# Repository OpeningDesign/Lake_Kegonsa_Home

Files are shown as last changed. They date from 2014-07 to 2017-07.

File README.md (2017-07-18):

Lake Kegonsa House
---

A major house renovation on [Lake Kegonsa](https://www.google.com/maps/place/3232+Aalseth+Ln,+Stoughton,+WI+53589/@42.94901,-89.25464,17z/data=!3m1!4b1!4m2!3m1!1s0x88064f5076276249:0x2fda5a143436c772)

Similar to our [IFCopenHouse](https://github.com/OpeningDesign/IFCopenHouse_Lantern_Hollow) we're using this open source project to try and push [openBIM](http://www.buildingsmart.org/standards/technical-vision/) even further.

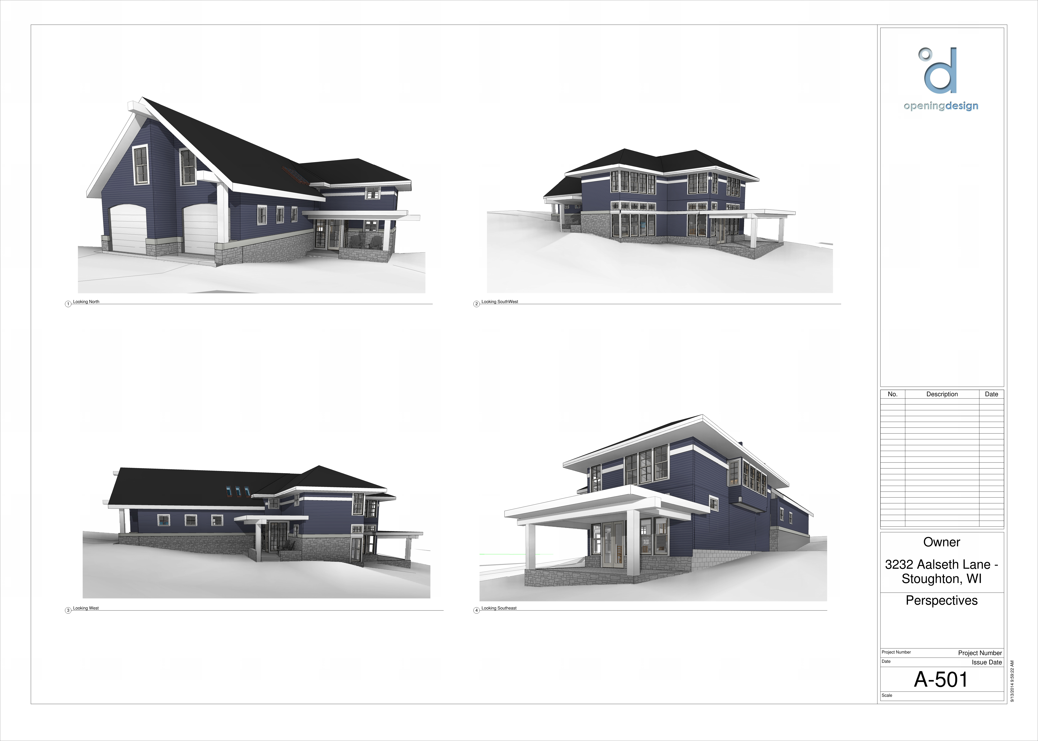
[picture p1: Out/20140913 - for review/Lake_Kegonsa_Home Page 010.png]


---
We are always looking to collaborate with a select team of individuals who are also excited about the benefits of working  <a href="#in-the-open">in the open</a> and pushing the bounds of existing and new IFC workflows.

One of our mantras is, "Specialize, Specialize, Specialize!".  Over the years we would like to build a trusted network of highly specialized collaborators agile enough to tackle the most obscure problems.

Although, currently we're looking for a **structural engineer** to collaborate with on this project, if you're a AEC consultant also interested in this 'open' way of working, shoot us an email at <ahref="mailto:hello@openingdesign.com">hello@openingdesign.com</a>. It would be great to work with you in the future.

* Architectural Technologist
* Civil Engineer
* Code Expediter/Consultant
* Electrical Engineer
* Energy Conservation Consultant
* Environmental Engineer
* Estimators
* Fabricators
* Geotechnical Engineer
* Landscape Architect
* Lighting Designer
* Mechanical Engineer
* Plumbing Engineer
* Specification Writer
* Structural Engineer
* Sub-contractors
* And of course, most importantly, *Building & Facility Owners*. :)

---
#### In-the-Open

All of OpeningDesign's projects are conducted out in the open.  That is, during the development of any one project, all team communication and content is hosted [publicly](https://github.com/OpeningDesign) and is <a href="#license">open source</a>.

Since we believe that [innovation happens elsewhere](https://www.google.com/search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) we would like to lower, as much as possible, the barrier for others to collaborate and contribute.

---
#### License
Per usual, all [OpeningDesign](http://openingdesign.com) content is licensed under an open source, 'copyleft' license: 
Attribution-ShareAlike 4.0 International (CC BY-SA 4.0)


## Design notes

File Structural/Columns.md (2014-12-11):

**Column Analysis. Columns at Axis 3, Axis 7**

**1. Sketch.**

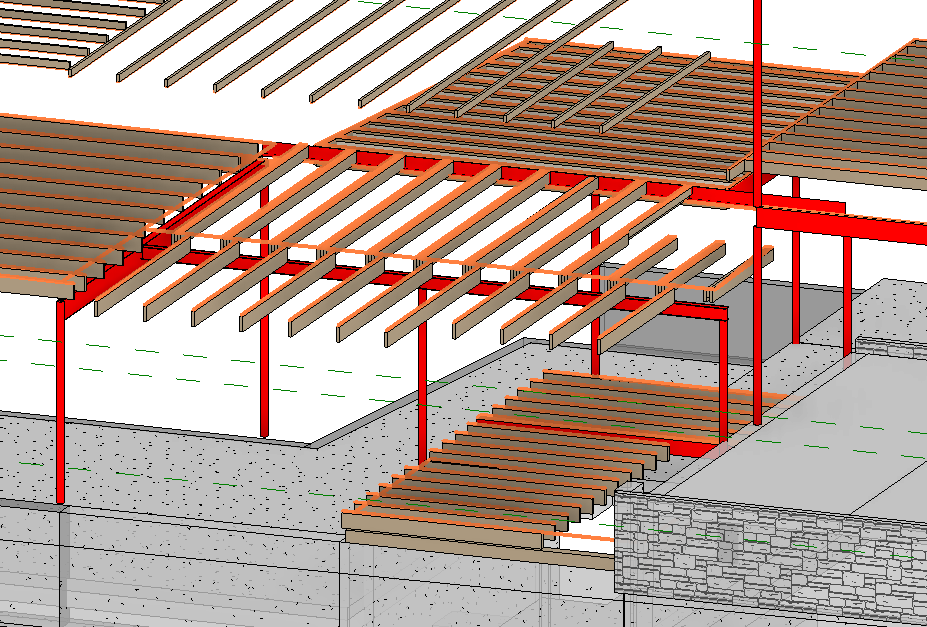
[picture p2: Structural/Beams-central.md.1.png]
Sketch


**2. Input Summary.**

2.1. Applicable codes.
2.1.1. Wisconsin Administrative Code, Chapter SPS 321 – Uniform Dwelling Code
2.1.2. ASCE 07-05, Minimum Loads on Buildings
2.1.3. AISC 360-05, Specification for Structural Steel Buildings

2.2. Design considerations.
As per 2.1.1, allowable stress design (ASD) is performed for steel elements using 2.1.3.

2.3. Load values

Dead Load Calculation:
Minimum value: 							Dmin = 10 psf;
Flooring: Wood Joists w/ Wood flooring 	D1 = approx. 12 psf;
Walls: light-frame wood walls			D2 = approx 6 psf
Max D1+D2+D3 & Dmin						D = D1+D2 = 18 psf

D = 18 psf		as per WAC Chapter SPS 321, calculation
L = 40 psf		as per WAC Chapter SPS 321 Table 321.02

**3. Structural Design.**

3.1 Columns at gridline (4).

3.1.1. Column at gridline (4D)

	Material 		= A500 Steel ASTM.
	Unbraced length = 7.58'

Loads Calculation from Beams-Central reactions calc (3.2.1):

	Total Point Load 	= R1 = 4.57 kip
	Dead Load 			= 1.4 		kip
	Live Load			= 3.17 		kip

ASD Design as per 2.1.1. SPS 

	Section		= HSS3.5X.188
	Fy			= 42 ksi
	Fu			= 58 ksi
	Compression/buckling checks apply.

3.1.2. Column at gridline (4F)

	Material 		= A500 Steel ASTM.
	Unbraced length = 7.58'

Loads Calculation from Beams-Central reactions calc (R2 from 3.2.1):

	Total Point Load 	= R2 	= 13.84 	kip
	Dead Load 					= 4.33 		kip
	Live Load					= 9.51 		kip

ASD Design as per 2.1.1. SPS 

	Section		= HSS3.5X.188
	Fy			= 42 ksi
	Fu			= 58 ksi
	Compression/buckling checks apply.

3.1.3. Column at gridline (4H)

	Material 		= A500 Steel ASTM.
	Unbraced length = 9.9'

Loads Calculation from Beams-Central reactions calc (R3 from 3.2.1, R2 from 3.3.1):

	Total Point Load 	= R3 +R2	= 3.67+5.33 = 9.0 	kip
	Dead Load 									= 2.8 	kip
	Live Load									= 6.2 	kip

ASD Design as per 2.1.1. SPS 

	Section		= HSS3.5X.188
	Fy			= 42 ksi
	Fu			= 58 ksi
	Compression/buckling checks apply.

3.2. Columns at gridline (2).

Material:	A500 Steel ASTM.

	Unbraced length = 11.3’

Loads Calculation (worst case)

	Load Area 		= 14 x 8 = 112 sf.
	Dead Load 		= 112 x 18 = 2.1 kip
	Live Load		= 112 x 40= 4.5 kip

ASD Design as per 2.1.1. SPS 

Section		= HSS3.5X.188

	Fy			= 42 ksi
	Fu			= 58 ksi
	Compression/buckling checks apply.

**4. Design Results**
	
4.1 Columns at gridline (4).

Unbraced: 		= A500 Gr. B Steel, HSS Shape HSS3.5X.188 (see Calculation 3.1.)

4.2. Columns at gridline (2).

Unbraced: 		= A500 Gr. B Steel, HSS Shape HSS3.5X.188 (see Calculation 3.2.)

Calculation 3.1.

Only governing calculation for columns (4F) and (4H) are shown

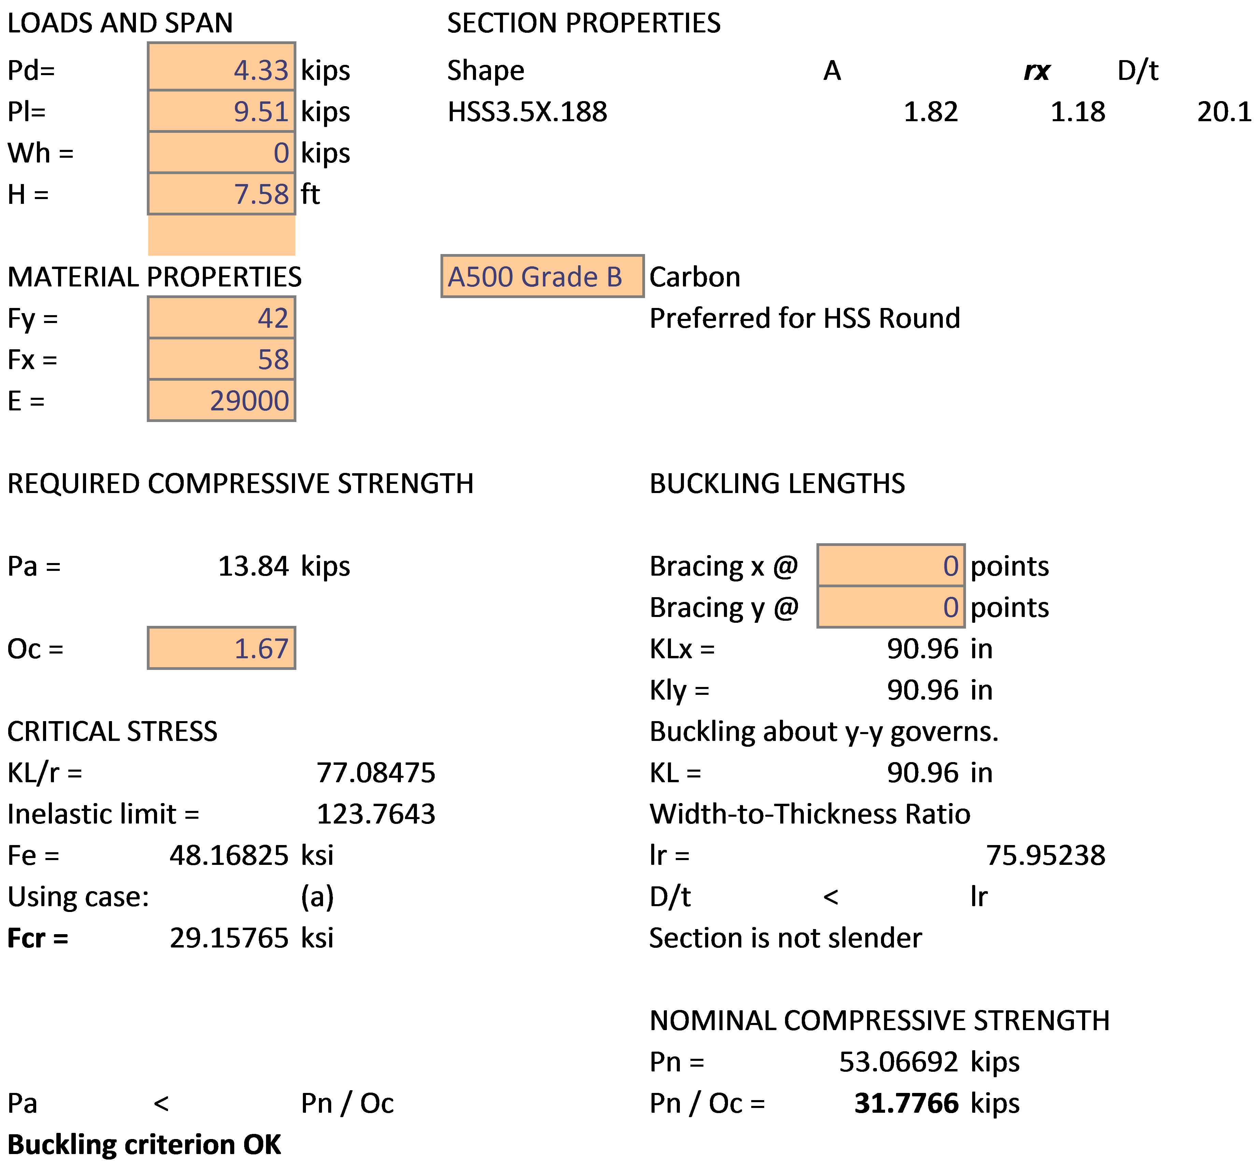
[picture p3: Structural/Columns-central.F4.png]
Calc 3.1.2


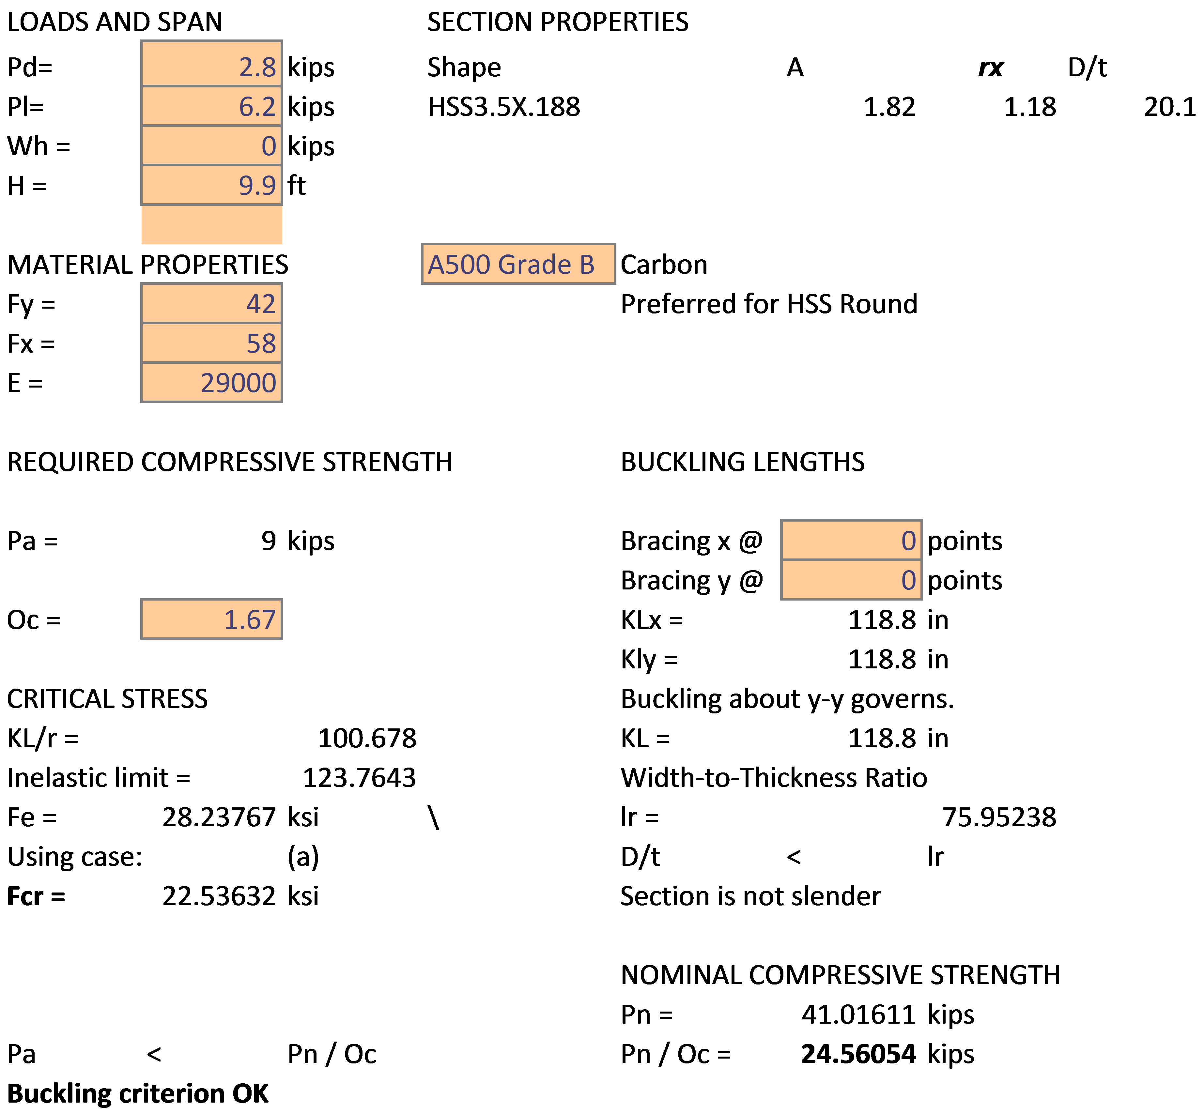
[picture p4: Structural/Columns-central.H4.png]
Calc 3.1.3


Calculation 3.2.
 
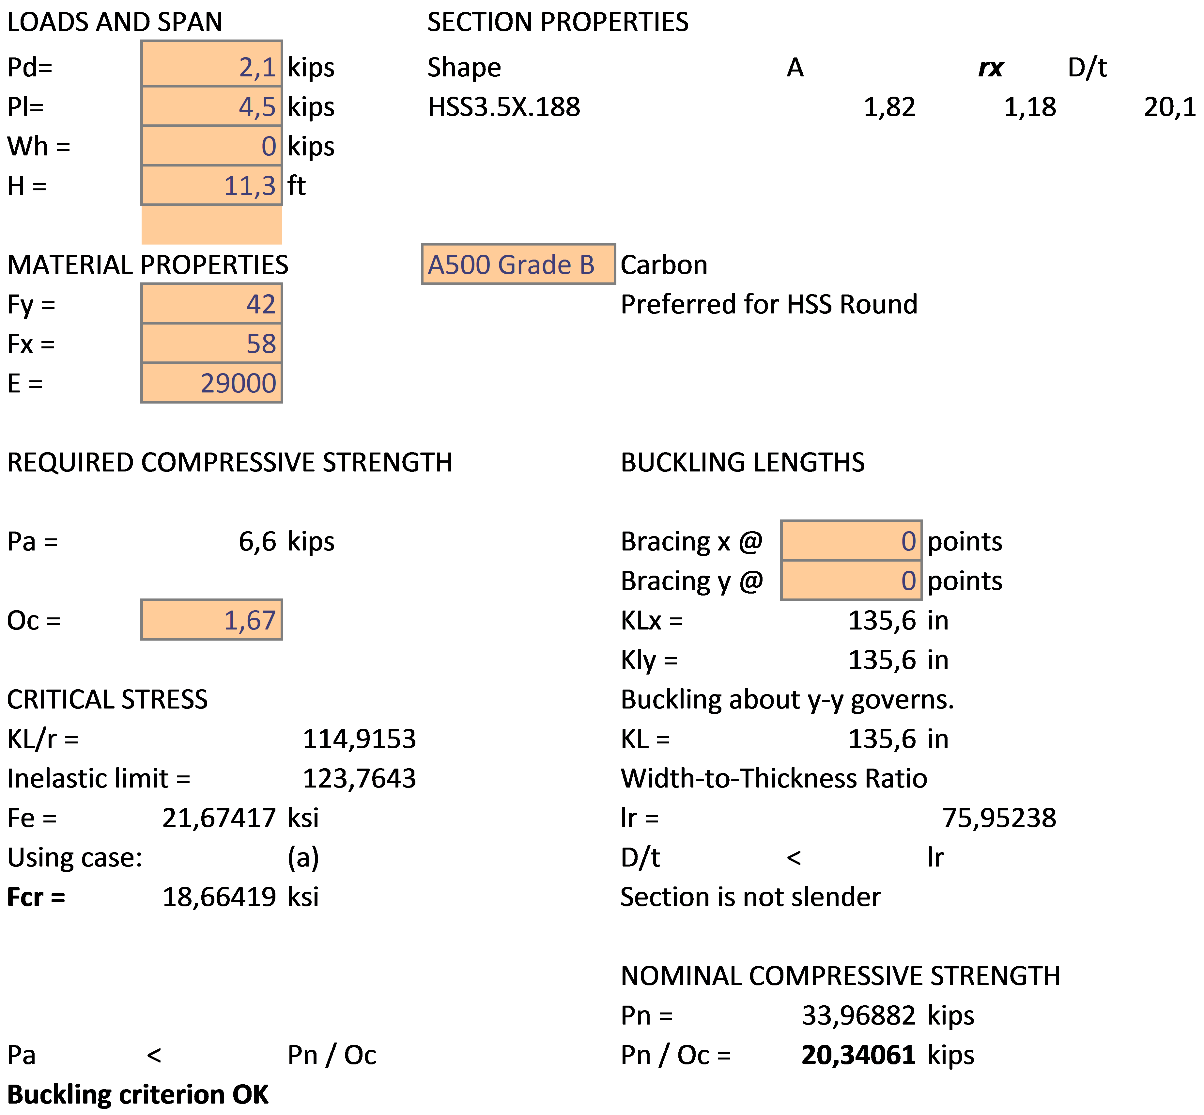
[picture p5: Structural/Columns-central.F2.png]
Calc 3.2


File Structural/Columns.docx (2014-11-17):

Column Analysis. Columns at Axis 3, Axis 7

1. Sketch.


2. Input Summary.

2.1. Applicable codes.
2.1.1. Wisconsin Administrative Code, Chapter SPS 321 – Uniform Dwelling Code
2.1.2. ASCE 07-05, Minimum Loads on Buildings
2.1.3. AISC 360-05, Specification for Structural Steel Buildings

2.2. Design considerations.

As per 2.1.1, allowable stress design (ASD) is performed for steel elements using 2.1.3.

2.3. Load values

Dead Load Calculation:

Minimum value: Dmin = 10 psf;

Flooring: Wood Joists w/ Wood flooring D1 = approx. 12 psf;

Walls: light-frame wood walls D2 = approx 6 psf

Max D1+D2+D3 & Dmin D = D1+D2 = 18 psf

D = 18 psf as per WAC Chapter SPS 321, calculation
L = 40 psf as per WAC Chapter SPS 321 Table 321.02

3. Structural Design.

3.1. Columns at Axis 3.

Material: A500 Steel ASTM.

Unbraced length = 8.2’

Loads Calculation (worst case)

Load Area = 13 x 11.5 = 150 sf.

Dead Load = 150 x 18 = 2.7 kip

Live Load = 150 x 40= 6 kip

AISC Check

ASD Design as per 2.1.1. SPS

Section = HSS3.5X.188

Fy = 42 ksi

Fu = 58 ksi

Compression/buckling checks apply.

3.1. Columns at Axis 7.

Material: A500 Steel ASTM.

Unbraced length = 11.3’

Loads Calculation (worst case)

Load Area = 14 x 8 = 112 sf.

Dead Load = 112 x 18 = 2.1 kip

Live Load = 112 x 40= 4.5 kip

AISC Check

ASD Design as per 2.1.1. SPS

Section = HSS3.5X.188

Fy = 42 ksi

Fu = 58 ksi

Compression/buckling checks apply.

4. Design Results

4.1 Columns at Axis 3.

Unbraced: = A500 Gr. B Steel, HSS Shape HSS3.5X.188 (see Calculation 3.1.)

4.2. Columns at Axis 7.

Unbraced: = A500 Gr. B Steel, HSS Shape HSS3.5X.188 (see Calculation 3.2.)

Calculation 3.1.

Calculation 3.2.

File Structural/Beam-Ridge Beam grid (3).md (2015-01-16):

# 1. Sketch.

Sketch

# 2. Input Summary.

## 2.1. Applicable codes.  
2.1.1. Wisconsin Administrative Code, Chapter SPS 321 – Uniform Dwelling Code  
2.1.2. ASCE 07-05, Minimum Loads on Buildings    
  
## 2.2. Design considerations.

Span tables are used to determine minimal section.

Reference design: Weyerhaeuser Microllam LVL Beams p.14-15

<http://www.woodbywy.com/document/TJ-9000/>

## 2.3. Load values

S = 30 (22,5) psf	as per 2.1.1 SPS 321.27

W = 15 psf

## 3. Structural Design.

    Rafter Span = 12'
    Column Span = 16.8'
    Largest cantilever length = 10'5"
    Slope 10”/12” = 40°
	30 psf Live Load
	15 psf Dead Load
		
## 4. Design Results

Preliminary span tables results (excluding cantilever):

    Ridge Beam along Grid (3):
	Section: 3.5" x 14"

	Applicable Materials:
	1) 1.55E TimberStrand® LSL 
	2) 2.0E Microllam® LVL
	3) 2.0E Parallam® PSL

FINAL span tables results (including cantilever):
	
From max distributed load values derived from span tables:

	W = M / 50 = 12.13 * 2 / 50 = 0.49 kip/ft
	W = V / 10 = 4.6 * 2 / 10 = 0.92 kip/ft

Moment governs section design.

Considering span and cantilever moments equality:

	wl^2/8 = wa^2/2 => l = 2a,

Equivalent column span for cantilevered beam is:

	l = 2a = 2 * 10'5" = 21 ft
    
    Ridge Beam along Grid (3) Result:
	Section: 3½" x 16" OR 5¼" x 14"

	Applicable Materials:
	1) 2.0E Microllam® LVL
	)2 2.0E Parallam® PSL

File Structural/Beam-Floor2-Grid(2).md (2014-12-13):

# 1. Sketch.

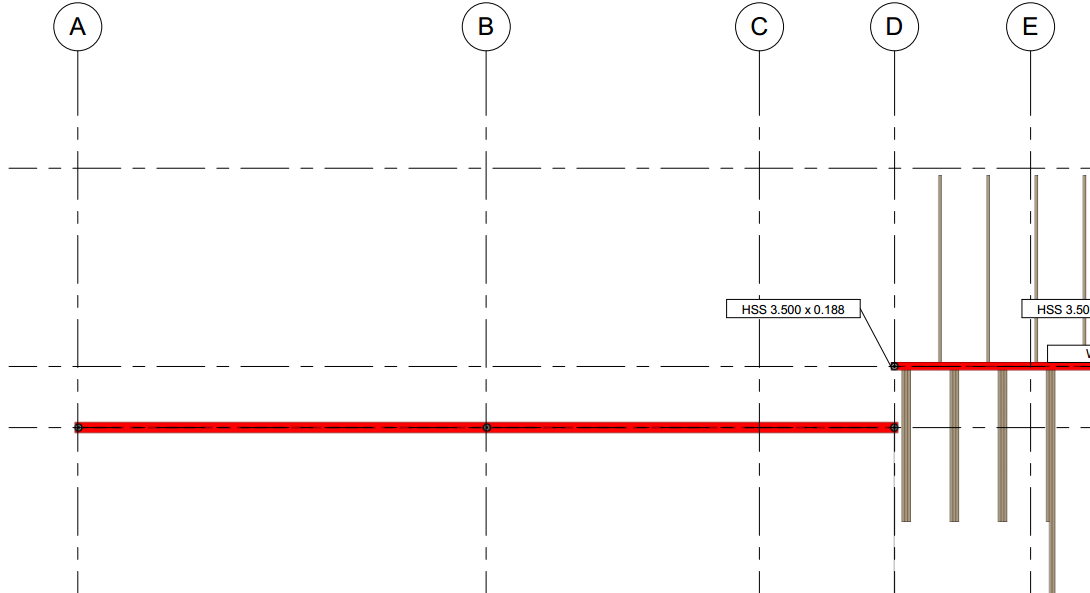
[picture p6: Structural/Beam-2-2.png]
Sketch


# 2. Input Summary.

## 2.1. Applicable codes.  
2.1.1. Wisconsin Administrative Code, Chapter SPS 321 – Uniform Dwelling Code  
2.1.2. ASCE 07-05, Minimum Loads on Buildings  
2.1.3. AISC 360-05, Specification for Structural Steel Buildings  

## 2.2. Design considerations.

As per 2.1.1, allowable stress design (ASD) is performed for steel elements using 2.1.3.

## 2.3. Load values

### Dead Load Calculation:

Minimum value:                 Dmin = 10 psf;

Dead Load, Roof:

    Minimum value:                 Dmin = 10 psf;
    Flooring: Wood Joists w/ Wood flooring     D1 = approx. 12 psf;
    Walls: light-frame wood walls        D2 = approx 6 psf;
    Max D1+D2 & Dmin            **D = D1+D2 = 18 psf**

### Live Load Calculation:

**L** = 40 psf        as per WAC Chapter SPS 321 Table 321.02

**D** = 18 psf        
**L** = 40 psf        

## 2.4. Load calculation

    Load span 1 = 6'

    Load span 2 = 7'

    Load length = 16.7'

    Load area = (6+7)*16.7 = 217.1 sq.ft.

    D = 18 * 13 = 0.234 kip/ft

    L = 40 * 13 = 0.520 kip/ft

## 3. Structural Design.

    Initial material:    A99 Steel ASTM.

    Beam span = 16.7'

AISC Check

    ASD Design as per 2.1.1. SPS

Section        = **W8X24**

    All considered sections are compact, Y and LBW checks apply.

Unbraced beam at (C):  = A992 Steel, W Shape **W8X24** (see Calculation)

## Calculation

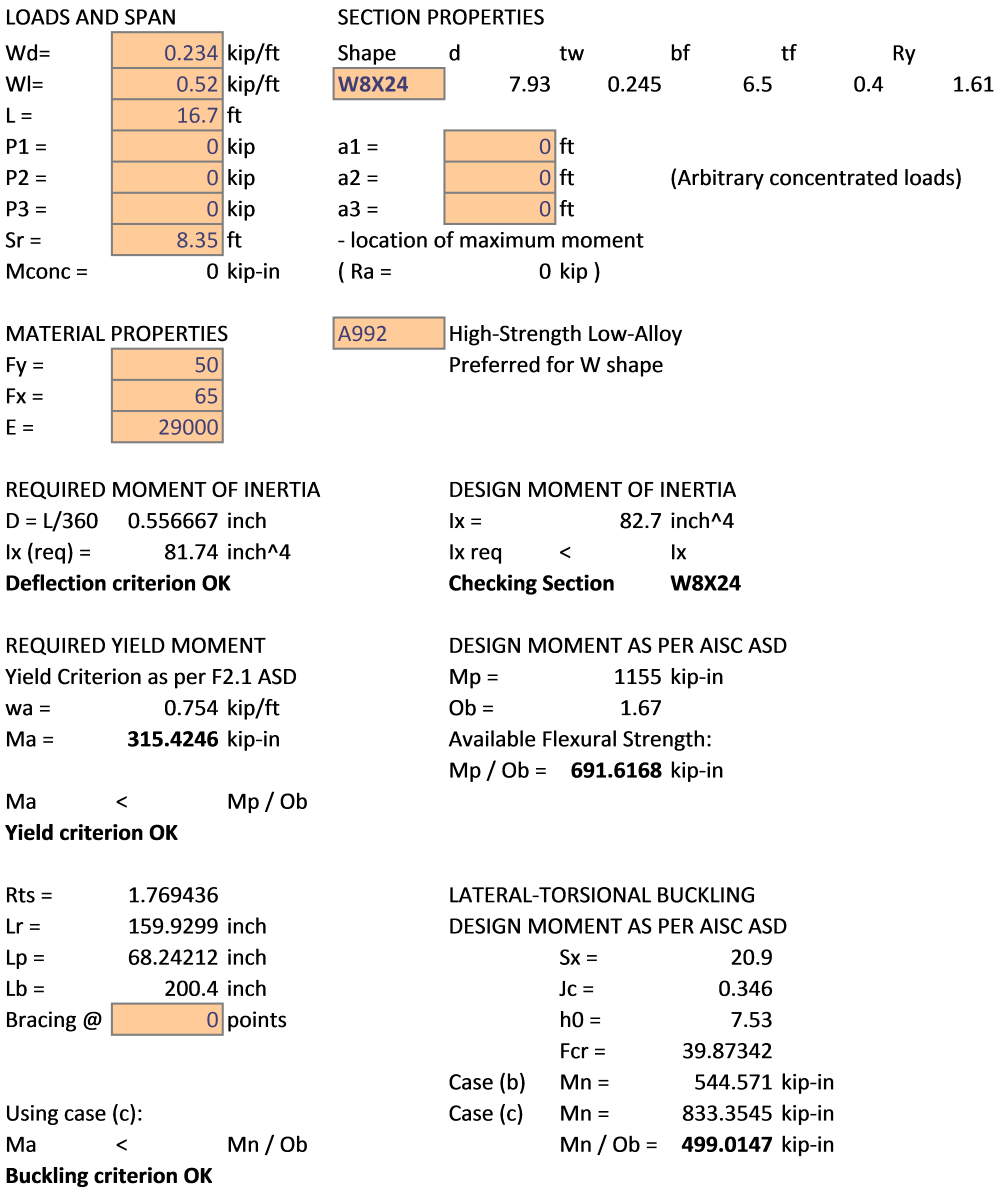
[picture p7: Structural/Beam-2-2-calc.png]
Calculation


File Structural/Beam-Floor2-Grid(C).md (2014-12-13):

# 1. Sketch.

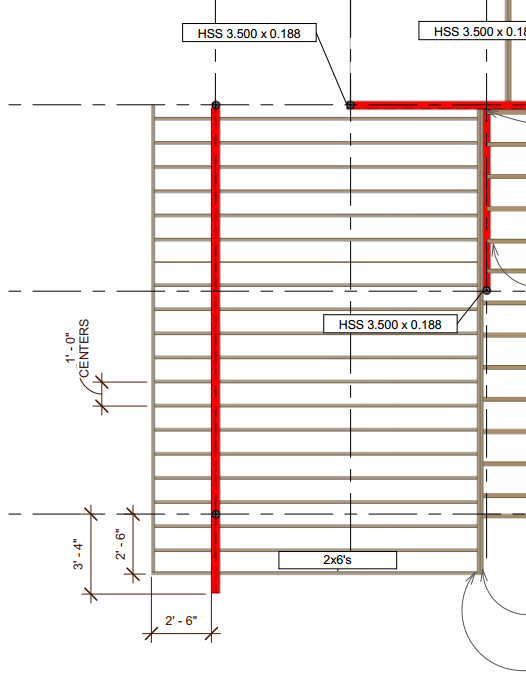
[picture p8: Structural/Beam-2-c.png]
Sketch


# 2. Input Summary.

## 2.1. Applicable codes.  
2.1.1. Wisconsin Administrative Code, Chapter SPS 321 – Uniform Dwelling Code  
2.1.2. ASCE 07-05, Minimum Loads on Buildings  
2.1.3. AISC 360-05, Specification for Structural Steel Buildings  

## 2.2. Design considerations.

As per 2.1.1, allowable stress design (ASD) is performed for steel elements using 2.1.3.

## 2.3. Load values

### Dead Load Calculation:

Minimum value:                 Dmin = 10 psf;

Dead Load, Roof:

Minimum value:          Dmin = 10 psf;

Rafters                 D1 = 3 psf;

Plywood & sheathing     D2 = 3psf/inch * 0.75 = 2.25 psf

Roofing                 D3 = 2 psf

Max D1+D2+D3 & Dmin     **D = 10 psf**

### Dead Load Calculation:

Snow Load				= **24.3 psf** per calculation

**D** = 10 psf        
**L** = 24.3 psf        

## 2.4. Load calculation

    Load span 1 = 2.5'

    Load span 2 = 10.0'

    Load length = 20.58'

    Load area = 12.5 * 20.58 = 257.3 sq.ft.

    D = 10 * 12.5 = 0.125 kip/ft

    L = 24.3 * 12.5 = 0.304 kip/ft

## 3. Structural Design.

    Initial material:    A99 Steel ASTM.

    Beam span = 17.0'

AISC Check

    ASD Design as per 2.1.1. SPS

Section        = **W8X18**

    All considered sections are compact, Y and LBW checks apply.

Unbraced beam at (C):  = A992 Steel, W Shape **W8X18** (see Calculation)

## Calculation

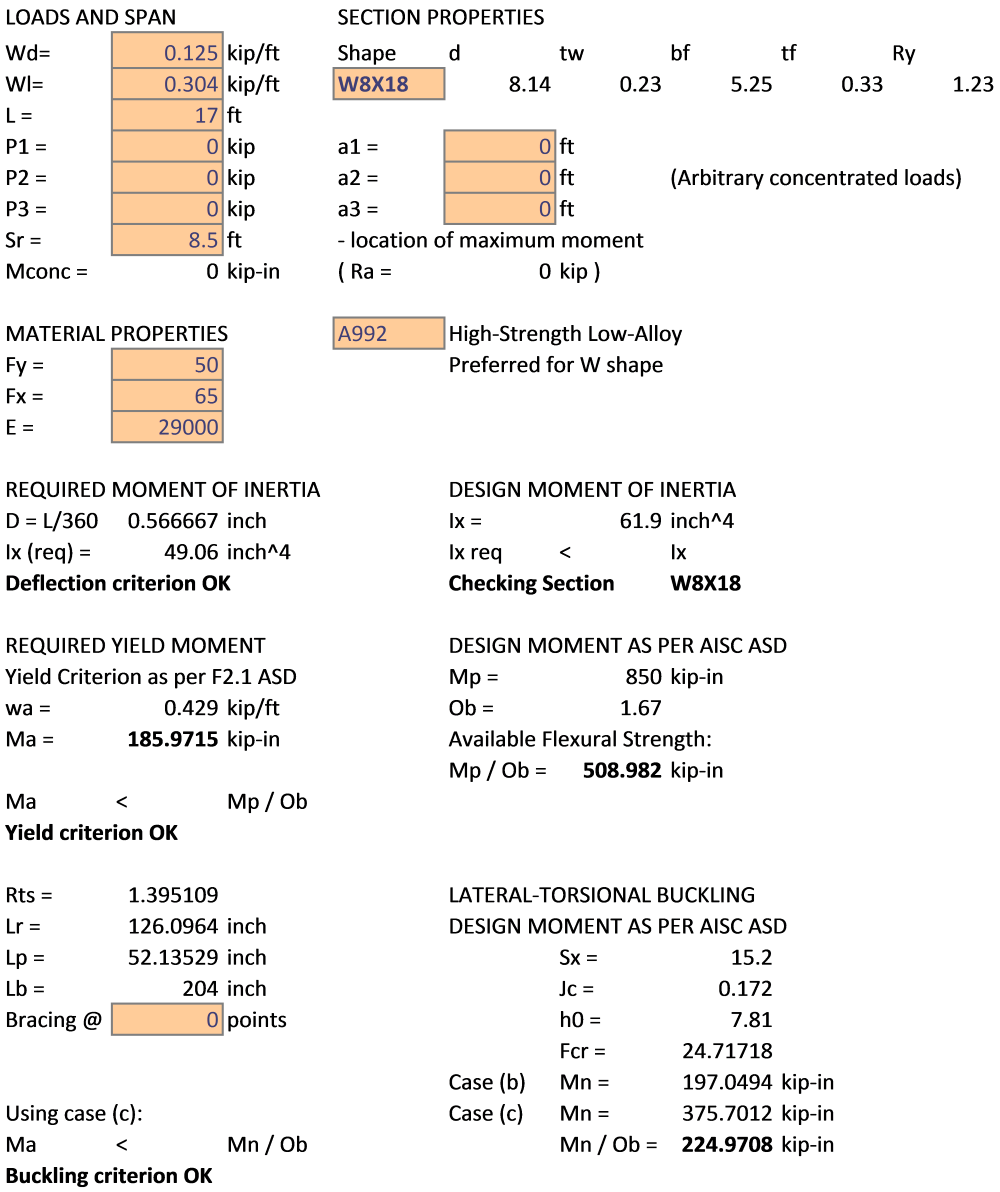
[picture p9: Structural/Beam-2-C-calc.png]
Calculation


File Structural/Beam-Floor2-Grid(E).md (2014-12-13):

# 1. Sketch.

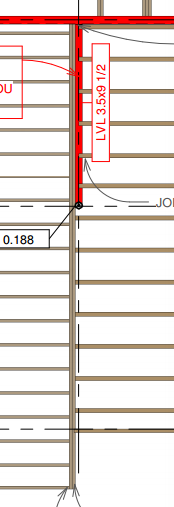
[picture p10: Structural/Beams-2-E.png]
Sketch


# 2. Input Summary.

## 2.1. Applicable codes.  
2.1.1. Wisconsin Administrative Code, Chapter SPS 321 – Uniform Dwelling Code  
2.1.2. ASCE 07-05, Minimum Loads on Buildings  
2.1.3. AISC 360-05, Specification for Structural Steel Buildings  

## 2.2. Design considerations.

Span tables are used to determine minimal section.

Reference design: Weyerhaeuser Microllam LVL Beams p.14-15

<http://www.woodbywy.com/document/TJ-9000/>

## 2.3. Load values

Dead Load Calculation:

Minimum value:                 Dmin = 10 psf;

Flooring: Wood Joists w/ Wood flooring     D1 = approx. 12 psf;

Walls: light-frame wood walls        D2 = approx 6 psf

Max D1+D2+D3 & Dmin            **D = D1+D2 = 18 psf**

**D** = 18 psf        as per WAC Chapter SPS 321, calculation  
**L** = 40 psf        as per WAC Chapter SPS 321 Table 321.02

## 3. Structural Design.

    Load Span 1 = 10.67'

    Load Span 2 = 17.0'

    Beam Span = 8.67'

## 4. Design Results

Floor 2 – Beam at grid (E):

Minimum design section 3.5" x 9.5"

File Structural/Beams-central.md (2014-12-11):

**1. Sketch.**

Sketch

**2. Input Summary.**

2.1. Applicable codes.  
2.1.1. Wisconsin Administrative Code, Chapter SPS 321 – Uniform Dwelling Code  
2.1.2. ASCE 07-05, Minimum Loads on Buildings  
2.1.3. AISC 360-05, Specification for Structural Steel Buildings  

2.2. Design considerations.

As per 2.1.1, allowable stress design (ASD) is performed for steel elements using 2.1.3.

2.3. Load values

Dead Load Calculation:

Minimum value:                 Dmin = 10 psf;

Flooring: Wood Joists w/ Wood flooring     D1 = approx. 12 psf;

Walls: light-frame wood walls        D2 = approx 6 psf

Max D1+D2+D3 & Dmin            **D = D1+D2 = 18 psf**

Snow Load				= **15.9 psf**

**D** = 18 psf        as per WAC Chapter SPS 321, calculation  
**L** = 40 psf        as per WAC Chapter SPS 321 Table 321.02

**3. Structural Design.**

3.1. Floor 2, Central Beam Design – Beam at grid (2).

3.1.1 Span 1

    Initial material:    A99 Steel ASTM.

    Span = 12.5'

    Length = 24.4'

Loads Calculation

    Load Area         = 12.5 x 12 = 150 sf.

    Dead Load         = 150 x 18 / 12.5 = 216 pf = 0.22 kip/ft

    Live Load        = 150 x 40 /12.5 = 480 pf = 0.48 kip/ft

AISC Check

    ASD Design as per 2.1.1. SPS

Section        = **W6X16**

    Fy            = 50 ksi

    Fu            = 65 ksi

    All considered sections are compact, Y and LBW checks apply.

3.1.2 Span 2

    Initial material:    A99 Steel ASTM.

    Span = 11.7'

    Length = 24.4'

Loads Calculation

    Load Area         = 11.7 x 12 = 140.4 sf.

    Dead Load         = Wd = 140.4 x 18 / 11.7 = 216 pf = 0.22 kip/ft

Not a governing span – design as per 3.1.1. Calculations not required.

3.2.1 Floor 2, Lintel Beam Design – Beam at grid (4), uniform load + conc. load

    Initial material:    A36 Steel ASTM.

    Span = 12'

    Length = 24'

Loads Calculation

    Span 1:

Load Area         	= 12 x 7.5 	= 90 sf.
Roof/ceiling load span 		 	= 12 ft.

    Dead Load 1        		= 90 x 18 / 12 = 135 pf = 0.135 kip/ft

	Dead Load, Roof:
	Minimum value: 			Dmin = 10 psf;
	Rafters 				D1 = 3 psf;
	Plywood & sheathing 	D2 = 3psf/inch * 0.75 = 2.25 psf
	Roofing				    D3 = 2 psf
	Max D1+D2+D3 & Dmin		D = 10 psf

	Dead Load, Ceiling:		D1 (wood joists) 	= 0.85 psf
							D2 (gypsum 5/8")	= 2.75 psf
							D = D1 + D2 		= 3.6 psf
	Dead Load 2 			= (10 + 3.6) * 12 	= 0.163 kip/ft

	Snow Load Area:			2/5 of roof area

    Live Load        	= 90 x 40 /12 = 300 pf 	= 0.3 kip/ft
    Snow Load 			= 15.9 * 12 * 2/5 		= 0.076 kip/ft

    Span 2:

    Load Area 1        = 7.4 x 7.5 = 55.5 sf

    Load Area 2 (point)    = 13 x 7.3 = 94.9 sf

    Dead Load        = 55.5 x 18 / 12 = 0.083 kip/ft

    Live Load        = 55.5 x 40 / 12 = 0.185 kip/ft

    Point Dead Load    = 94.9 x 18 = 1.7 kip

    Point Live Load    = 94.9 x 40 = 3.8 kip

AISC Check

    ASD Design as per 2.1.1. SPS

    Initial section        = L8X4X9/16

    Fy            = 36 ksi

    Fu            = 58 ksi

    Y, LBW, LLB checks apply.

    Design values calculation:
    continuous beam, unequal spans, uniform load W + conc. load P

    Design moment of inertia :
    I = 2.33 * P + 31.6 * W = 12.82 + 21.3 = 34.12 in^4

    Design moment M:
    M = 0.844 * P + 19.2 * W = 210,9 kip*in

    Reactions at HSS columns gridlines (D), (F), (H) respectively:
    R1 = 2.27 + 2.3 	= 4.57 kip
    R2 = 10.31 + 3.53 	= 13.84 kip
    R3 =				= 3.67 kip

3.3.1 Floor 2, Beam at grid (H), uniform load + conc. load

    Initial material:    A99 Steel ASTM.

    Span = 20.75'

    Length = 20.75'

Loads Calculation

    Distr. Load Area        = 20.75 x 7 = 145.25 sf.

    Dead Load    		    = 145.25 x 18 / 20.75 = 126 pf = 0.126 kip/ft

    Live Load  		      	= 145.25 x 40 / 20.75 = 280 pf = 0.28 kip/ft

    Conc. load from 3.1.1	= 3wl/8 = 3 * 0.7 * 12 / 8 = 3.15 kip

    Reactions at HSS columns gridlines (1H), (4H), DL+LL, respectively:
    R1 = wl/2 + Pb/l        = 0.406*20.75/2 + 3.15*13.3/20.75 = 6.22 kip
    R2 = wl/2 + P(l-b)/l    = 0.406*20.75/2 + 3.15*7.45/20.75 = 5.33 kip

AISC Check

    ASD Design as per 2.1.1. SPS

Section        = **W12X26**

    Fy            = 50 ksi

    Fu            = 65 ksi

    All considered sections are compact, Y and LBW checks apply.

**4. Design Results**

4.1.1 Floor 2, Central Beam Design – Beam at grid (3).

Unbraced:                 = A992 Steel, W Shape **W6X16** (see Calculation 3.1.1.)

4.2. Floor 2, Lintel Beam Design – Beam at grid (4).  

Unbraced:                 = A36 Steel, L Shape **L8X4X9/16** (see Calculation 3.2.)

4.3. Floor 2, Main Beam Design – Beam at grid (H).  

Unbraced:                 = A992 Steel, W Shape **W12X26** (see Calculation 3.3.)

**Calculation 3.1.1.**

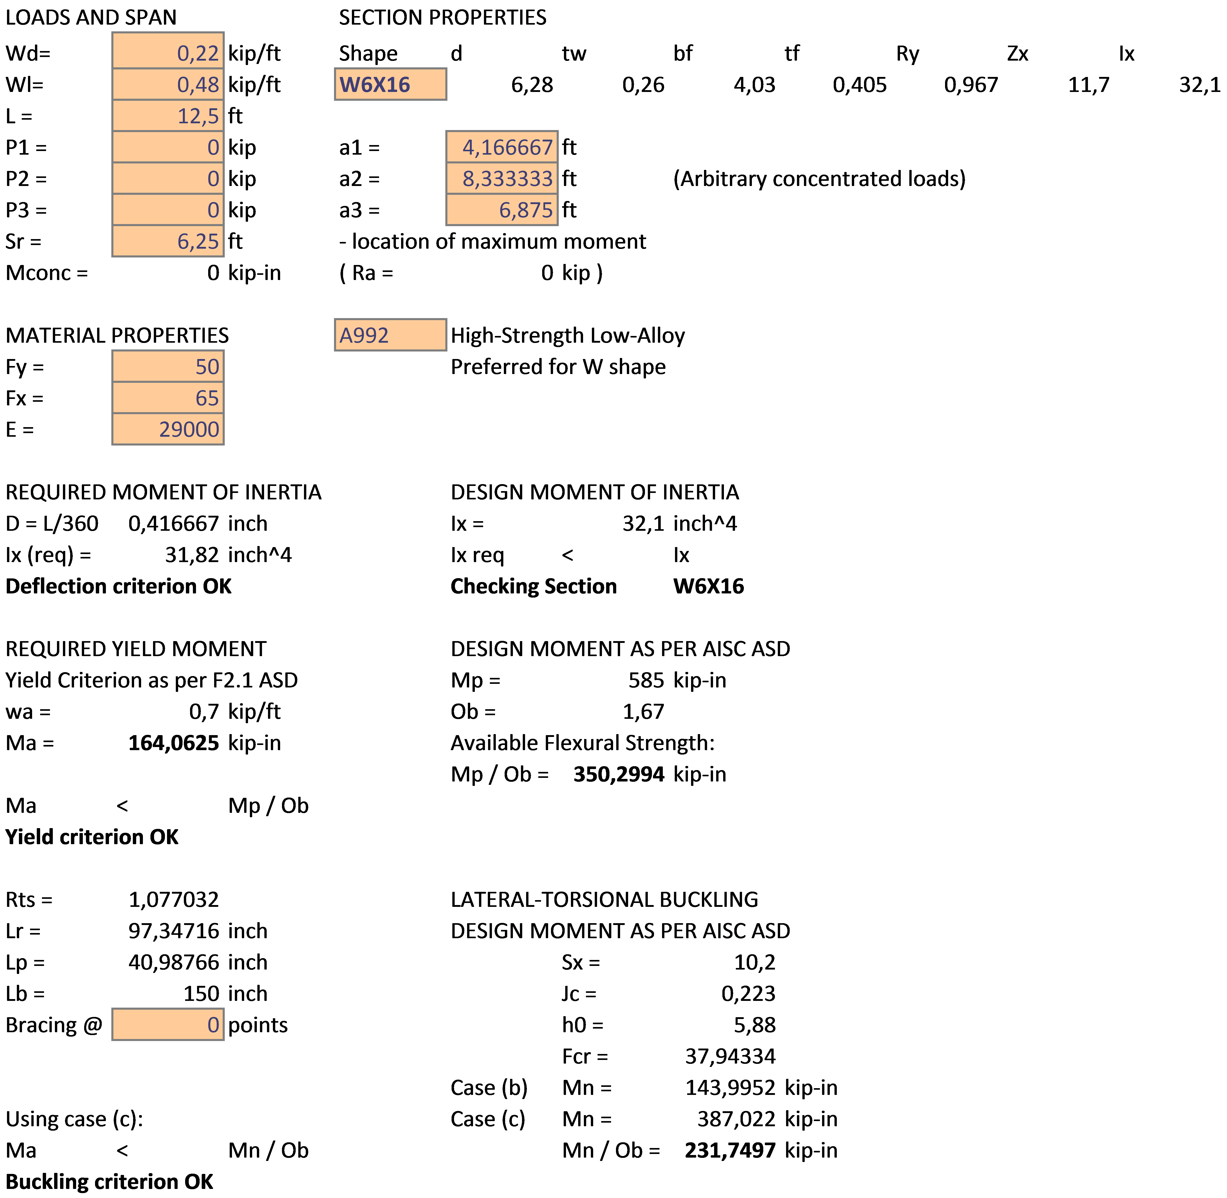
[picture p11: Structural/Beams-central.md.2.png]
Calc 3.1.1


**Calculation 3.2.**

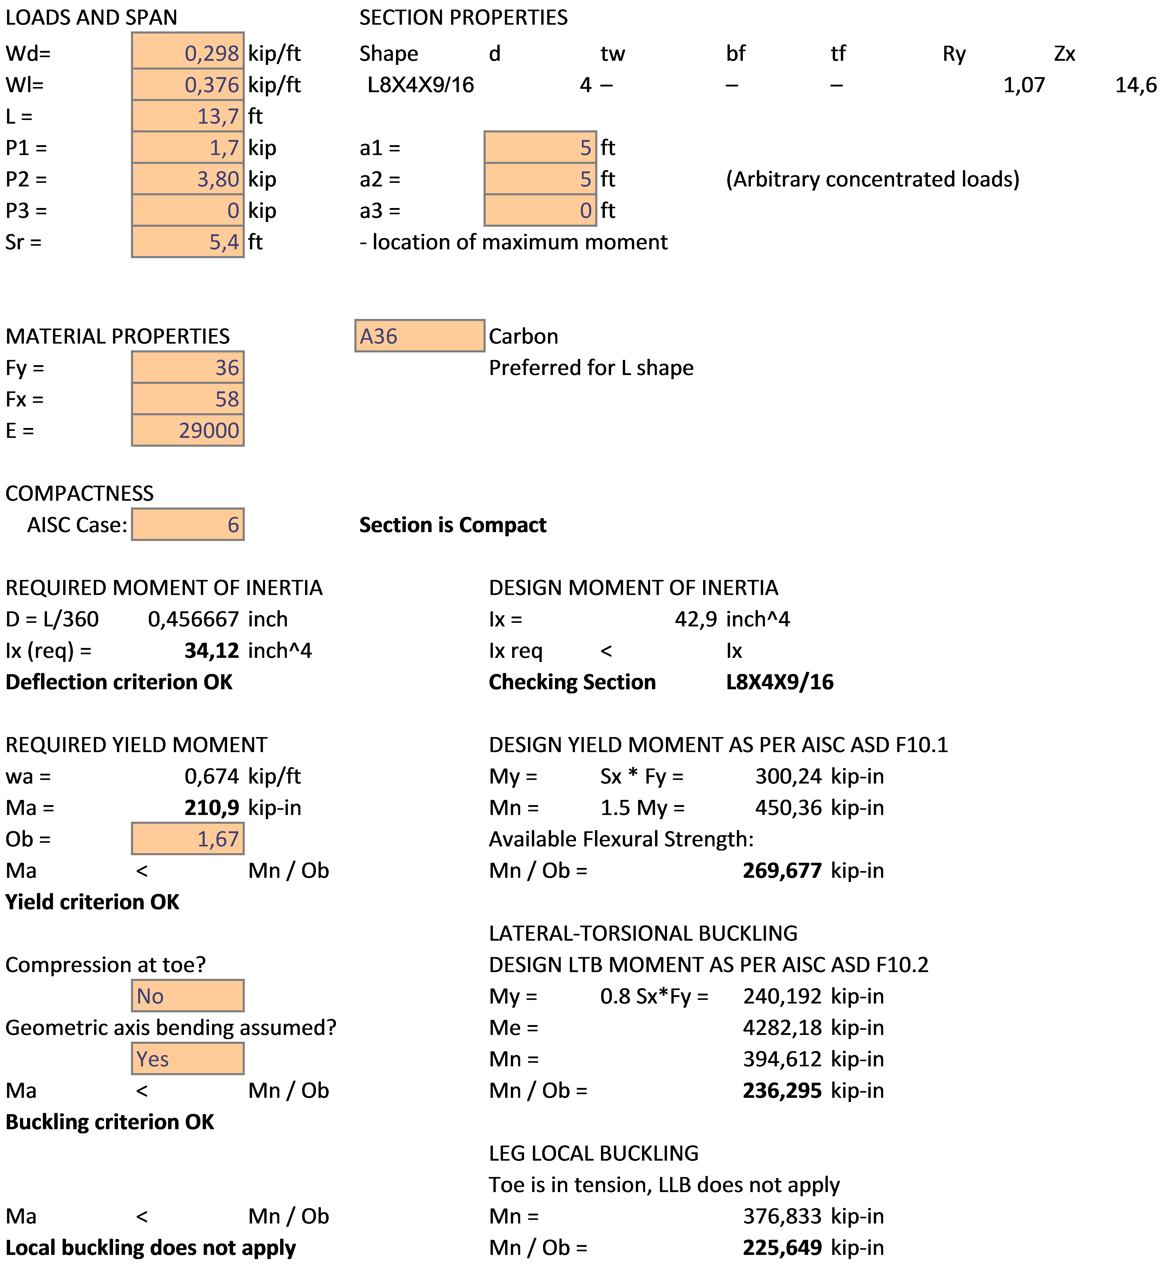
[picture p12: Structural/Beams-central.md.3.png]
Calc 3.2


**Calculation 3.3.**

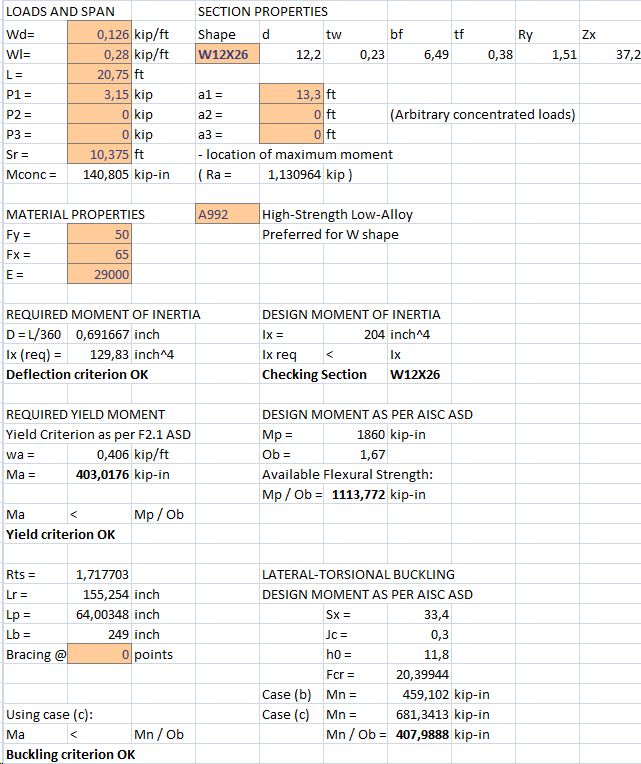
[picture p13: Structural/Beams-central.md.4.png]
Calc 3.3


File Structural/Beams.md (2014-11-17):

## Example Markdown Beam Design ##

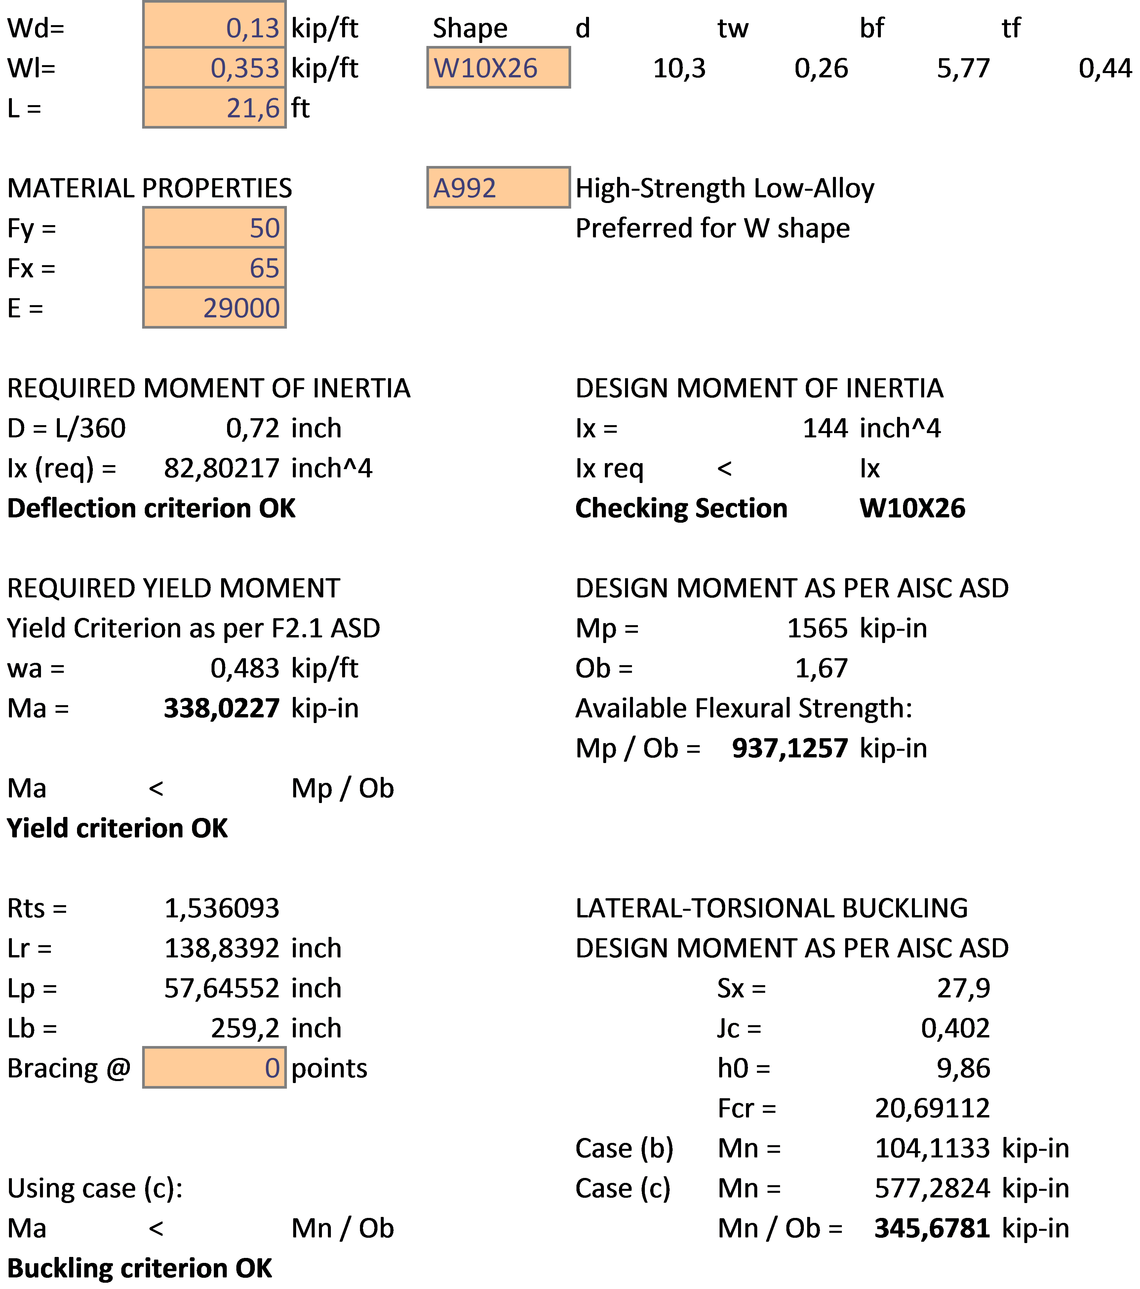
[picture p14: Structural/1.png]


-
-
-
-
-
-
-
-
-
-

| LOADS AND SPAN | | | SECTION PROPERTIES | | | | | |
| --- | --- | --- | --- | --- | --- | --- | --- | ---- |
| Wd= | 0,13 | kip/ft  | Shape  | d | tw | bf | tf | Ry | Zx | Ix  | Sx | J | ho |
| Wl= | 0,353 | kip/ft  | W10X26 | 10,3 | 0,26 | 5,77 | 0,44 | 1,36 | 31,3 | 144 | 27,9 | 0,402 | 9,86 |
| L = | 21,6 | ft | | | | | | | | | | | |
| | | | | | | | | | | | | | |
| MATERIAL PROPERTIES | | | A992 | High-Strength Low-Alloy | | | | | | | | | |
| Fy = | 50 | | | Preferred for W shape | | | | | | | | | |
| Fx = | 65 | | | | | | | | | | | | |
| E = | 29000 | | | | | | | | | | | | |
| | | | | | | | | | | | | | |
| REQUIRED MOMENT OF INERTIA | | | | DESIGN MOMENT OF INERTIA | | | | | | | | | |
| D = L/360 | 0,72 | inch | | Ix = | 144 | inch^4 | | | | | | | |
| Ix (req) = | 82,80217291 | inch^4  | | Ix req | < | Ix | | | | | | | |
| Deflection criterion OK | | | | Checking Section | | W10X26 | | | | | | | |
| | | | | | | | | | | | | | |
| REQUIRED YIELD MOMENT | | | | DESIGN MOMENT AS PER AISC ASD | | | | | | | | | |
| Yield Criterion as per F2.1 ASD | | | | Mp = | 1565 | kip-in | | | | | | | |
| wa = | 0,483 | kip/ft  | | Ob = | 1,67 | | | | | | | | |
| Ma = | 338,02272 | kip-in  | | Available Flexural Strength:  | | | | | | | | | |
| | | | | Mp / Ob = | 937,1257485 | kip-in | | | | | | | |
| Ma | < | Mp / Ob | | | | | | | | | | | |
| Yield criterion OK | | | | | | | | | | | | | |
| | | | | | | | | | | | | | |
| Rts = | 1,536093205 | | | LATERAL-TORSIONAL BUCKLING | | | | | | | | | |
| Lr = | 138,8392288 | inch | | DESIGN MOMENT AS PER AISC ASD | | | | | | | | | |
| Lp = | 57,64552157 | inch | | | Sx = | 27,9 | | | | | | | |
| Lb = | 259,2 | inch | | | Jc = | 0,402 | | | | | | | |
| Bracing @ | 0 | points  | | | h0 = | 9,86 | | | | | | | |
| | | | | | Fcr = | 20,69112477 | | | | | | | |
| | | | | Case (b) | Mn = | 104,1132572 | kip-in | | | | | | |
| Using case (c): | | | | Case (c) | Mn = | 577,282381  | kip-in | | | | | | |
| Ma | < | Mn / Ob | | | Mn / Ob = | 345,6780724 | kip-in | | | | | | |
| Buckling criterion OK | | | | | | | | | | | | | |

[logo]: 1.png "Logo Title Text 2"

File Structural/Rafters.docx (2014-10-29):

1. Sketch.

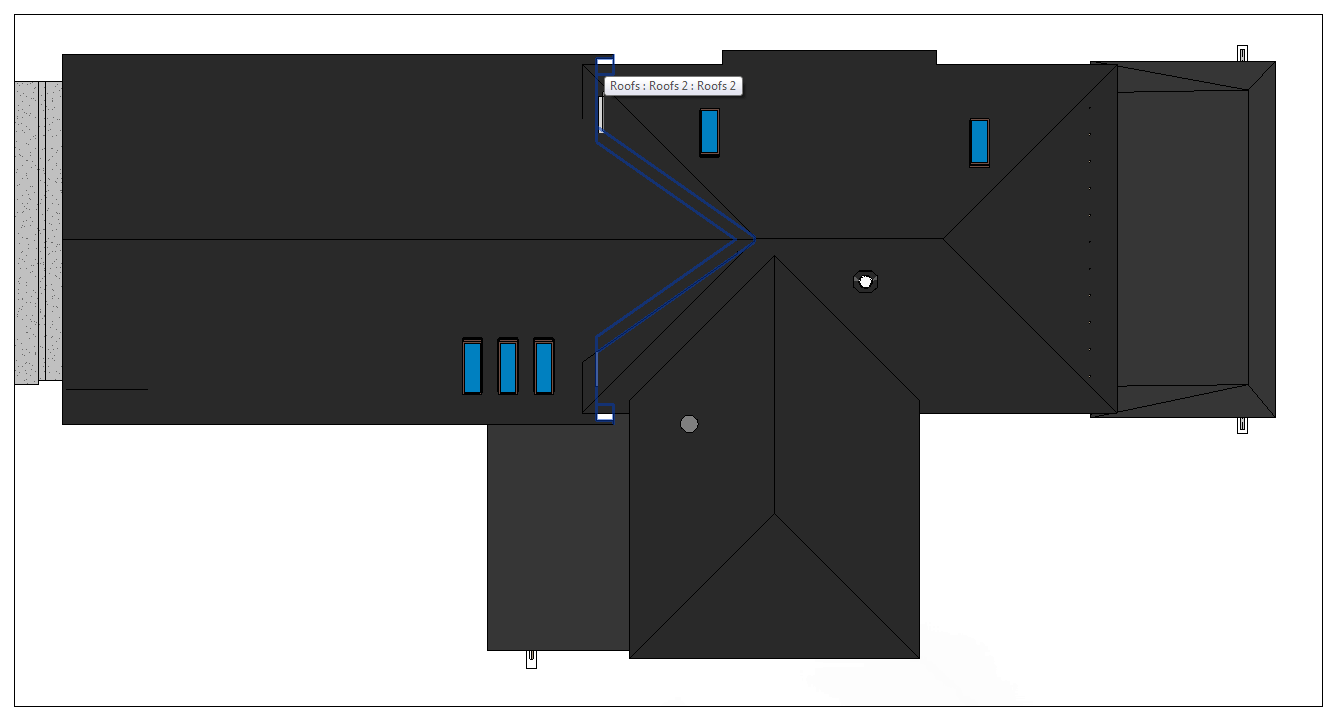
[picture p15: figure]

2. Global input data.

2.1. Applicable codes.
2.1.1. Wisconsin Administrative Code, Chapter SPS 321 – Uniform Dwelling Code
2.1.2. ASCE 07-05, Minimum Loads on Buildings
2.1.3. AISC 360-05, Specification for Structural Steel Buildings

2.2. Load combinations.
As per 2.1.2, Load combinations are:
1.4D
1.2D + 1.6L + 0.5Lr
1.2D + 1.6L + 0.5S
1.2D + 1.6Lr + L
1.2D + 1.6S + L
1.2D + 1.0W + L + 0.5(Lr or S or R)
0.9D + 1.0W

Span tables design

2.3. Load values

L = 40 psf as per 2.1.1 Table 321.02, 2.1.2 Table 4-1
LrC = 300 lbs as per 2.1.2 Table 4-1
S = 30 (22,5) psf as per 2.1.1 SPS 321.27
W = 20 psf as per 2.1.1 SPS 321.02

3. Elements subject to design.

3.1. Roof A-D, Garage storage:
Slope 10”/12” = 40°
8x2@16” Softwood – Pine, 34.9 pcf.

Span = 11’5”

Span tables check as per SPS 320-325: Table R-2:

Roof rafters 10”/12”,

30 psf Live Load,

10 psf Dead Load,

L/240 Maximum Deflection.

Rafter Bending Design Value Fb = 800 psi;

E = 0.57.

Grade examples that satisfy Fb include:

Spruce-Pine-Fir No.2 @16”

Southern Pine No.2 @16”

3.2. Roof I-J, Porch 1:
6x2@16” Softwood – Pine, density R = 34.9 pcf.

Span = 11’

L/240 Maximum Deflection.

Dead Load Calculation:

Minimum value: Dmin = 10 psf;

Rafters D1 = 2.9 psf;

Plywood & sheathing D2 = 3psf/inch * 0.75 = 2.25 psf

Roofing D3 = 2 psf

Max D1+D2+D3 & Dmin D = 10 psf

Snow Load Calculation:

See calc.3.2.

27.2 psf Live Load (incl. drift),

Span Tables Check as per SPS 320-325:

Rafter Bending Design Value Fb = 950 psi;

E = 0.85.

Grade and spacing examples that satisfy Fb include:

Spruce-Pine-Fir No.2 6x2 @ 12”

Southern Pine No.2 6x2 @ 12”

3.3. Roof C-D, Porch 2:
6x2@16” Softwood – Pine, 34.9 pcf.

Span = 10’4”

L/240 Maximum Deflection.

Dead Load Calculation:

Minimum value: Dmin = 10 psf;

Rafters D1 = 2.9 psf;

Plywood & sheathing D2 = 3psf/inch * 0.75 = 2.25 psf

Roofing D3 = 2 psf

Max D1+D2+D3 & Dmin D = 10 psf

Snow Load Calculation:

See calc.3.3.

27.3 psf Live Load (incl. drift),

Span Tables Check as per SPS 320-325:

Rafter Bending Design Value Fb = 850 psi;

E = 0.75.

Grade and spacing examples that satisfy Fb include:

Spruce-Pine-Fir No.2 6x2 @ 12”

Southern Pine No.2 6x2 @ 12”

Calculation for 3.2.

Calculation for 3.3.

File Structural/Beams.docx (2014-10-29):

1. Sketch.

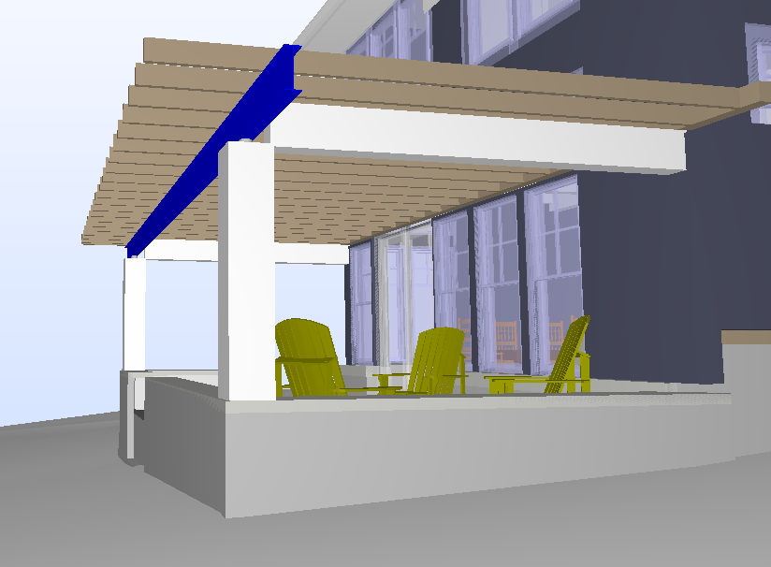
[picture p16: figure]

2. Input Summary.

2.1. Applicable codes.
2.1.1. Wisconsin Administrative Code, Chapter SPS 321 – Uniform Dwelling Code
2.1.2. ASCE 07-05, Minimum Loads on Buildings
2.1.3. AISC 360-05, Specification for Structural Steel Buildings

2.2. Design considerations.

As per 2.1.1, allowable stress design (ASD) is performed for steel elements using 2.1.3.

2.3. Load values

D = 10 psf as per Rafters calculations 3.2
S = 27.2 psf as per Rafters calculations 3.2
W = 20 psf as per 2.1.1 SPS 321.02

3. Structural Design.

3.1. Floor 1, Front Porch, Roof Beam Design.

Initial material: A99 Steel ASTM.

Span = 21.6’

Length = 28.25’

Loads Calculation

Load Area = 13.8 x 26.6 = 367 sf.

Dead Load = 367 x 10 / 28.25 = 130 pf = 0.13 kip/ft

Snow Load = 367 x 27.2 /28.25 = 353 pf = 0.353 kip/ft

AISC Check

ASD Design as per 2.1.1. SPS

Initial section = W10X15

Fy = 50 ksi

Fu = 65 ksi

All considered sections are compact, Y and LBW checks apply.

Design Results

Laterally braced at 2 points min: = A992 Steel, W Shape W10X19 (see Calculation 3.1.1.)

Unbraced: = A992 Steel, W Shape W10x26 (see Calculation 3.1.2.)

Calculation 3.1.1.

Calculation 3.1.2.

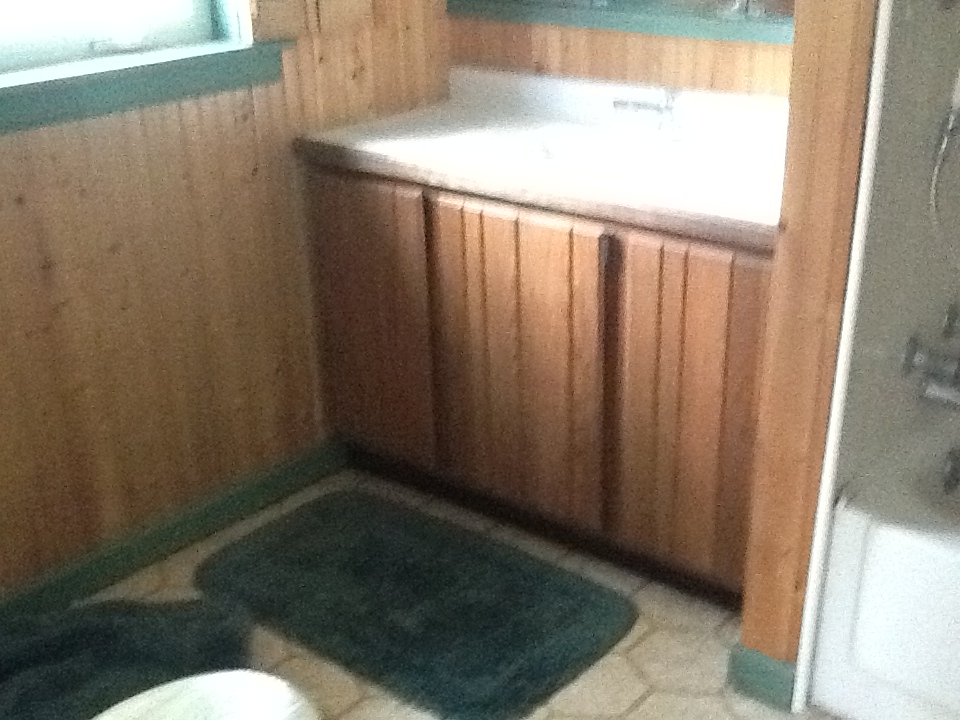
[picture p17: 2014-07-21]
As-built/site photos/2014-07-19 14.11.10.jpg

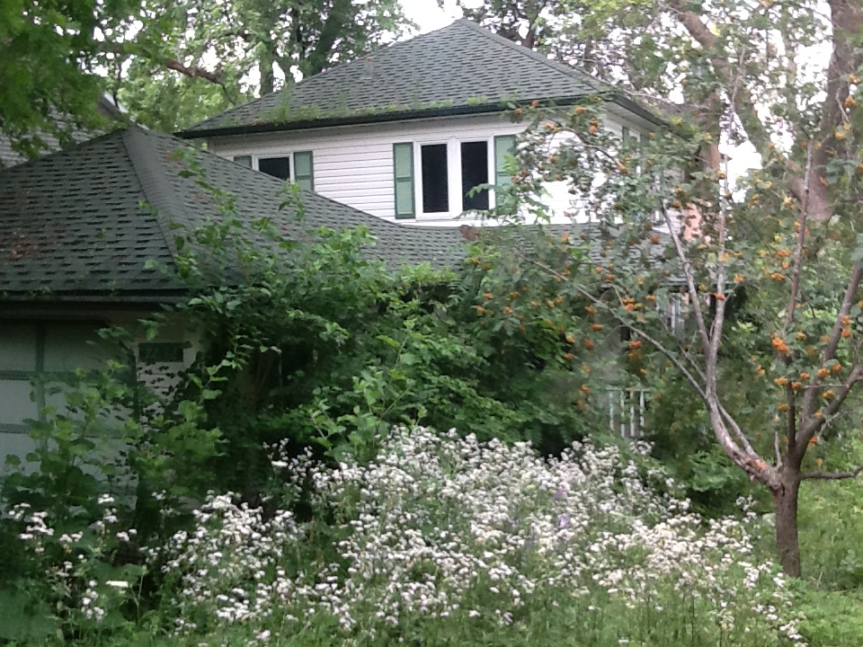
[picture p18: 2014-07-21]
As-built/site photos/2014-07-19 14.15.09.jpg

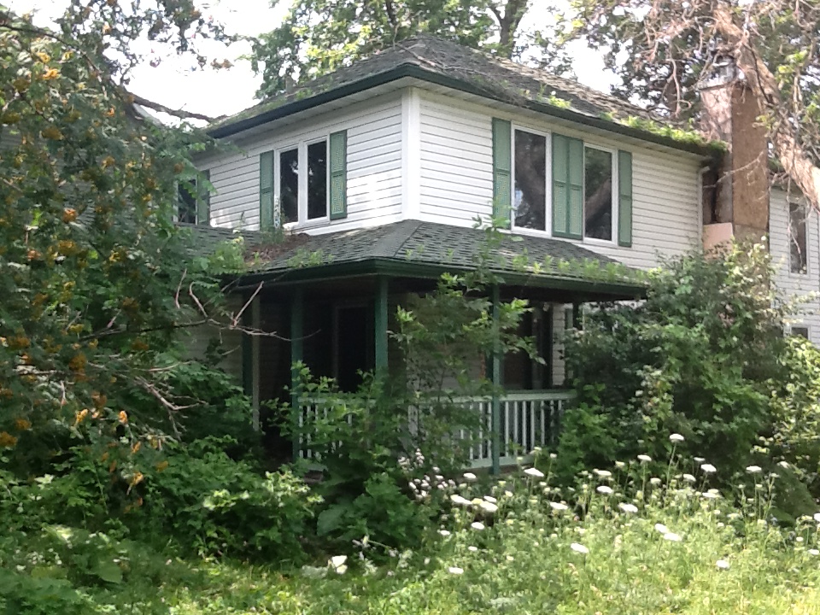
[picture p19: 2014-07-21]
As-built/site photos/2014-07-19 14.14.46.jpg

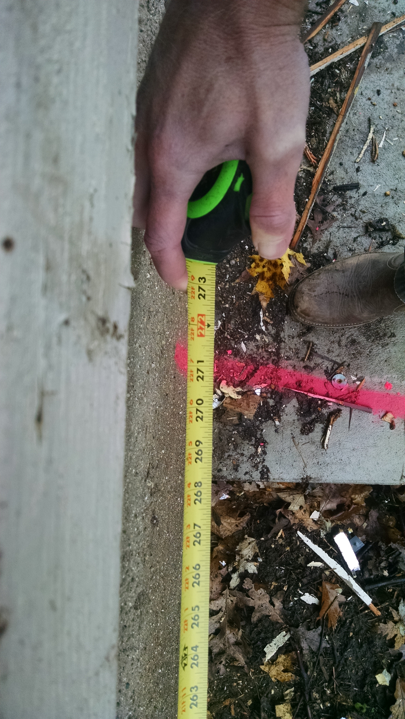
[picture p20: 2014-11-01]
As-built/Photos and Videos/2014-10-24 10.45.39.jpg

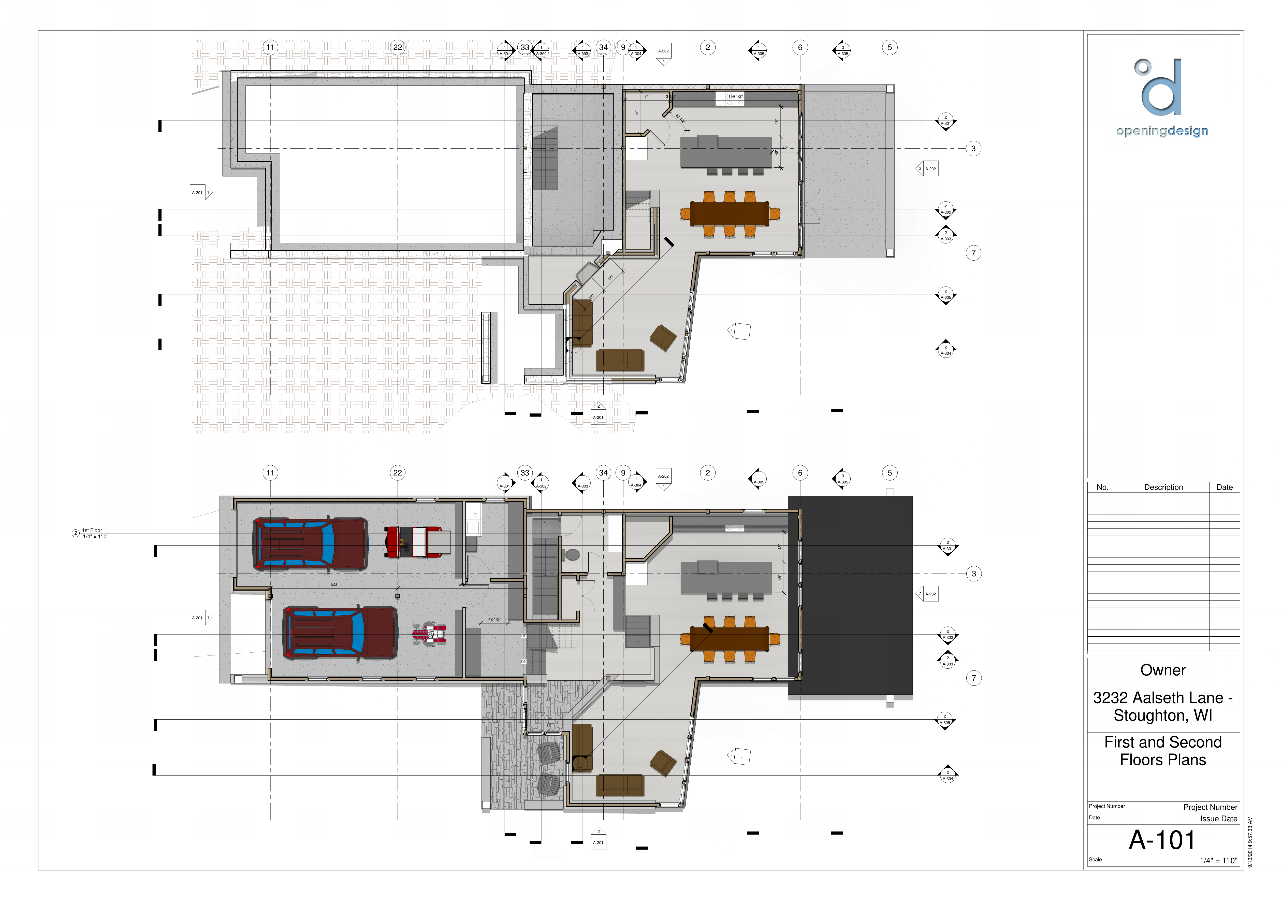
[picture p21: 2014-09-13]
Out/20140913 - for review/Lake_Kegonsa_Home Page 001.png

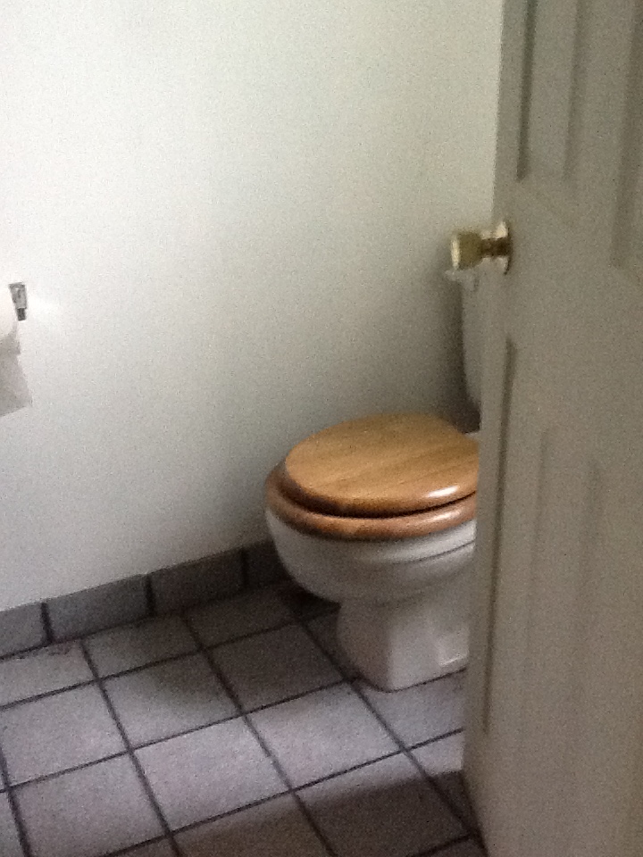
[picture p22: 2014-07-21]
As-built/site photos/2014-07-19 14.13.28.jpg

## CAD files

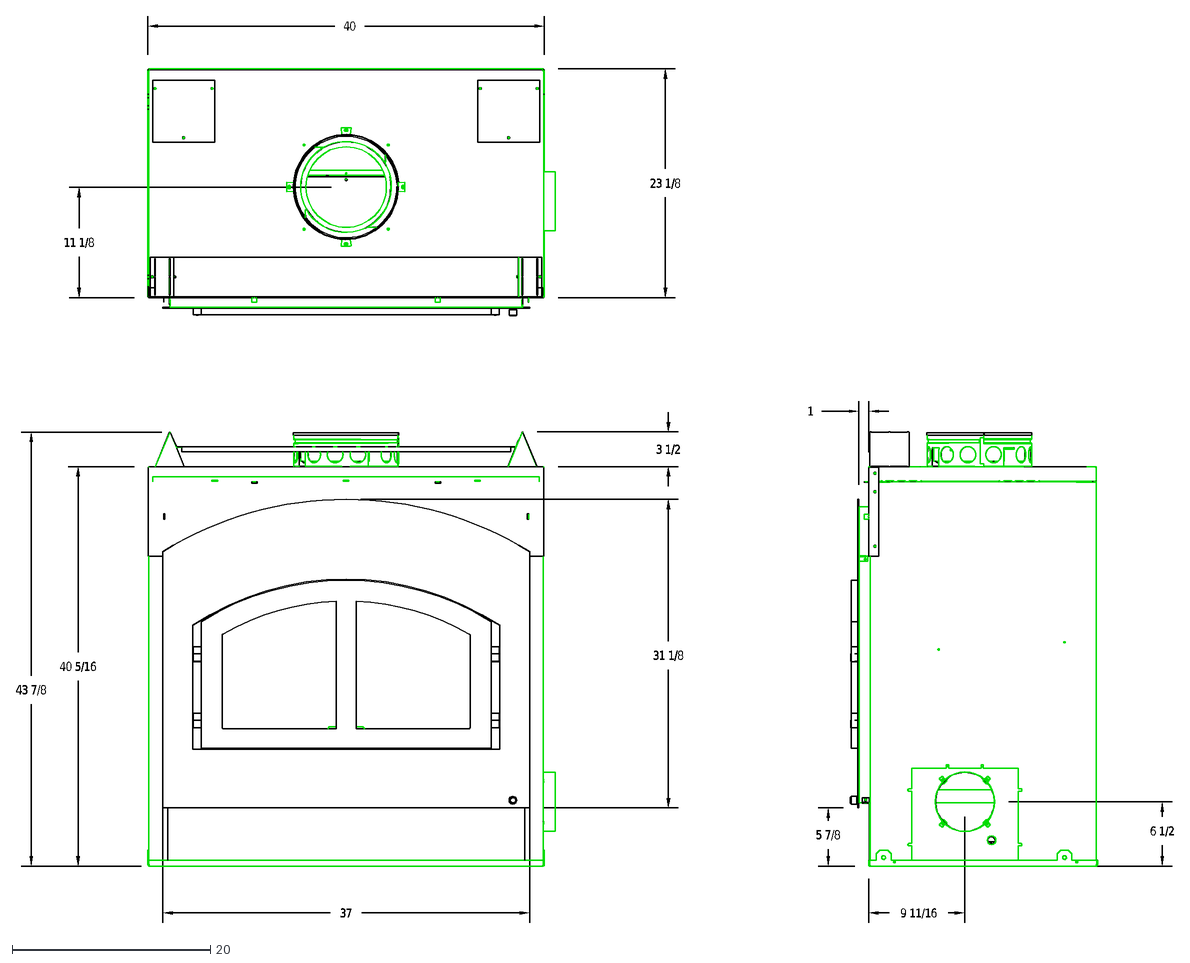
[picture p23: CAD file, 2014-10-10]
Model/northstar/northstar.dxf
40 5/16
9 11/16
6 1/2
23 1/8
11 1/8
5 7/8
1
31 1/8
37
3 1/2
40
43 7/8

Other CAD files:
As-built/WBlock from Paulson.dwg
Info/fireplace/7100fp/7100fp.dxf
Info/mouldings/Colonial-Revival-Moulding-Collection/KB Classical Moulding - Colonial Revival Profiles.dxf
Info/mouldings/Early-American-Moulding-Collection/KB Classical Moulding - Early American Profiles.dxf
Info/mouldings/Federal-Moulding-Collection/KB Classical Moulding - Federal Profiles.dxf
Info/mouldings/Georgian-Moulding-Collection/KB Classical Moulding - Georgian Profiles.dxf
Info/mouldings/Greek-Revival-Moulding-Collection/KB Classical Moulding - Greek Revival Profiles.dxf
Info/mouldings/KB-Classical-Moulding-Colonial-Revival-room-CAD/classical-moulding-colonial-revival-room-CAD/Colonial-Revival-Package.dxf
Info/mouldings/KB-Classical-Moulding-Federal-Room-CAD/classical-moulding-federal-room-CAD/Federal-Package.dxf
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

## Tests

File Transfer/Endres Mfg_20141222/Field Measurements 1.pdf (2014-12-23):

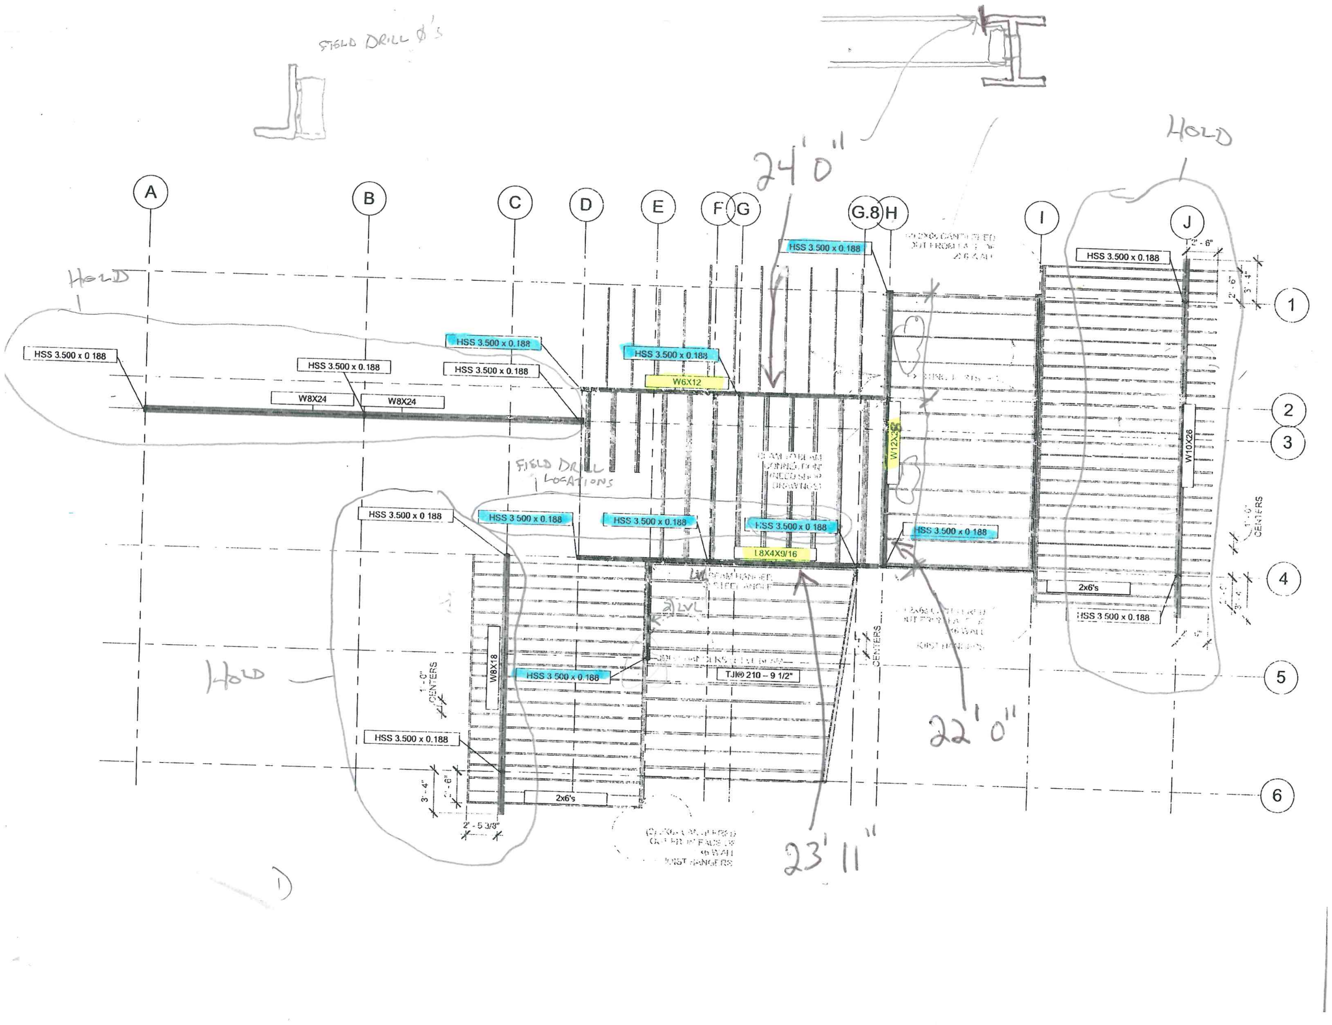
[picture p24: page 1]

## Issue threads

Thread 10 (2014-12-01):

Structural review of 2nd floor...

theoryshaw, 2014-12-01:
@bausk Can you review the following PDF?

Can you please verify i have all the correct sizes that you speced?

I also have a couple questions in red.

https://github.com/OpeningDesign/Lake_Kegonsa_Home/commit/514fbf20a0b1a5d8bb650f3cbc6738f2fd449e38

btw... please send along a jpg of your logo, if you have one.  Would like to add it to the title sheet, as well.

Closed 2015-01-06.

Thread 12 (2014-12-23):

Questions from Steel Supplier

theoryshaw, 2014-12-23:
Hey @bausk

Could you answer the following couple questions from the steel supplier?  Particularly questions (3) and (4).
Associated documents can be found here: https://github.com/OpeningDesign/Lake_Kegonsa_Home/commit/a5925e1124955b8893b7d240e0124c62587f89c9
or..
Lake_Kegonsa_Home\Transfer\Endres Mfg_20141222

>Before we make up a drawing for approval, please clarify.
 1)      We will be making the steel columns, using 3” sch. 40 pipe. We do have adjustable base for these, similar to the FHA posts.

I'm assuming this is okay.
> 2)      W12x28 – Your choice will be W12x26 or W12x30.

they read the plan wrong, it 'is' a W12x26.  It's the beam along H
>3)      L8x4x9/16” is not made. We have in stock L8x4x1/2 and I attached the mill certs with it. About 53 KSI. Can you make this work?

>4)      There is a double LVL connecting to the L8x4. Toby mentioned it would be difficult to determine exact location. Can you draw up some type of plate hanger similar to what I attached that would work. Toby said he would like to field drill the location into the L8x4.

bausk, 2015-01-04:
Ryan,
the initial sketch is okay to go but according to the IFC model, the LVL joists approach the lintel beam 2 3/4" lower compared bottom to bottom. I have added minor changes to the sketch to account for that, please view here:

https://github.com/OpeningDesign/Lake_Kegonsa_Home/commit/fbfa3e27eb721e9ff663f5c334403d16d1fea6b1

Since it is better practice to attach wood in the lower part of the section to prevent splintering, the mount holes for the LVL should be in the lower part of the LVL section.

Otherwise the sketch for question 4 is okay to go.

theoryshaw, 2015-01-05:
Thanks Alex
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

Closed 2015-01-06.

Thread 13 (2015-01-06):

remaining structural members

theoryshaw, 2015-01-06:
Hi @bausk

Can you size remaining members?  The following PDFs show their locations...
https://github.com/OpeningDesign/Lake_Kegonsa_Home/commit/dd375a52e1e2aac0b11baa330caaf871bec674b7

Not that alot has changed, but i also uploaded a new IFC file here, if you need it:
https://github.com/OpeningDesign/Lake_Kegonsa_Home/commit/e3574aeb474d02007898deb494126172e8806c05

They are starting to frame this week, so if you could get to these this week, that would ideal.

Thanks, Ryan

bausk, 2015-01-06:
Ryan, yes, absolutely, will do them asap (tomorrow is Orthodox Christmas
though so please take that into account)

On Tue, Jan 6, 2015 at 7:07 PM, Ryan Schultz <notifications@github.com>
wrote:

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

--
Alexander Bausk
IT Analyst, Structural engineer
MSc Structural engineering, Ph.C. Engineering
Professional blog at http://writandraw.org

theoryshaw, 2015-01-07:
Merry Christmas!... my kids would love two Christmases. ;)

For the ridge beam, was thinking it would be an LVL, so it's easier to tie in (nail in) the rafters.

Thanks.

bausk, 2015-01-12:
Ryan, please see the commit for basement LVLs:
https://github.com/OpeningDesign/Lake_Kegonsa_Home/commit/9a296bc2cb9c8a0ca406ebd9229f019eb4b13b74

I will also upload the ridge beam and accompanying pictures later in the day. Please inform me if we need to work out different sizes, esp. for the 11.25" one along grid (E).

bausk, 2015-01-16:
Ryan, please see the next commit for ridge beam:
https://github.com/OpeningDesign/Lake_Kegonsa_Home/commit/23a5086f42853d8350ffb516d2bce35e0a61efc2

Results for ridge beam are:
Section: 3½" x 16" OR 5¼" x 14"
This is slightly larger than in current model due to rather large cantilevered length.

bausk, 2015-01-16:
Ryan, I need a comment on the remaining beam in the roof floor along gridline (H). What is the purpose of that beam? From what I can get from the 3D model, it doesn't seem to support anything.

theoryshaw, 2015-01-16:
here's that condition... https://www.youtube.com/watch?v=vXK-MJ3R9ZU

It's a unique condition, not sure if there needs to be additional structure there.

theoryshaw, 2015-01-16:
fyi, those two 2x4 columns are temporary.

theoryshaw, 2015-01-28:
Discussed solution with @stevenuecke

bausk, 2015-02-03:
Ryan, an update on this issue: I have reviewed the video and don't see the need to add anything there, as far as can be seen from the available info

theoryshaw, 2015-02-05:
Alex, @stevenuecke suggested sistering a 2x10 along side that 2x4 ceiling joist and carrying the load down to the steel beam below.

Closed 2015-01-28.

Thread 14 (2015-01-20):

Minimum Suggested Bearing Width at Stone Ledge

theoryshaw, 2015-01-20:
@bausk Alex, would you happen to know the answer to this?...
http://www.eng-tips.com/viewthread.cfm?qid=378539

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

bausk, 2015-01-20:
Ryan, I would recommend to use the whole width of 4" even if the wall is
non-bearing, is that possible?

On Tue, Jan 20, 2015 at 3:07 AM, Ryan Schultz <notifications@github.com>
wrote:

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

--
Alexander Bausk
IT Analyst, Structural engineer
MSc Structural engineering, Ph.C. Engineering
Professional blog at http://writandraw.org

bausk, 2015-01-20:
Otherwise, the codes provide a minimum 2/3 of wythe thickness as a support
condition, that's 2 2/3 " in this case

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

--
Alexander Bausk
IT Analyst, Structural engineer
MSc Structural engineering, Ph.C. Engineering
Professional blog at http://writandraw.org

theoryshaw, 2015-01-21:
Thanks Alex.  Yes, 4" is unattainable in this scenario.

Closed 2015-01-21.

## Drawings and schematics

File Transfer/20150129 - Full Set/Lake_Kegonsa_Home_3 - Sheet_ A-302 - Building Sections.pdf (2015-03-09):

2 | 4
1 | 3 | 5 | 6

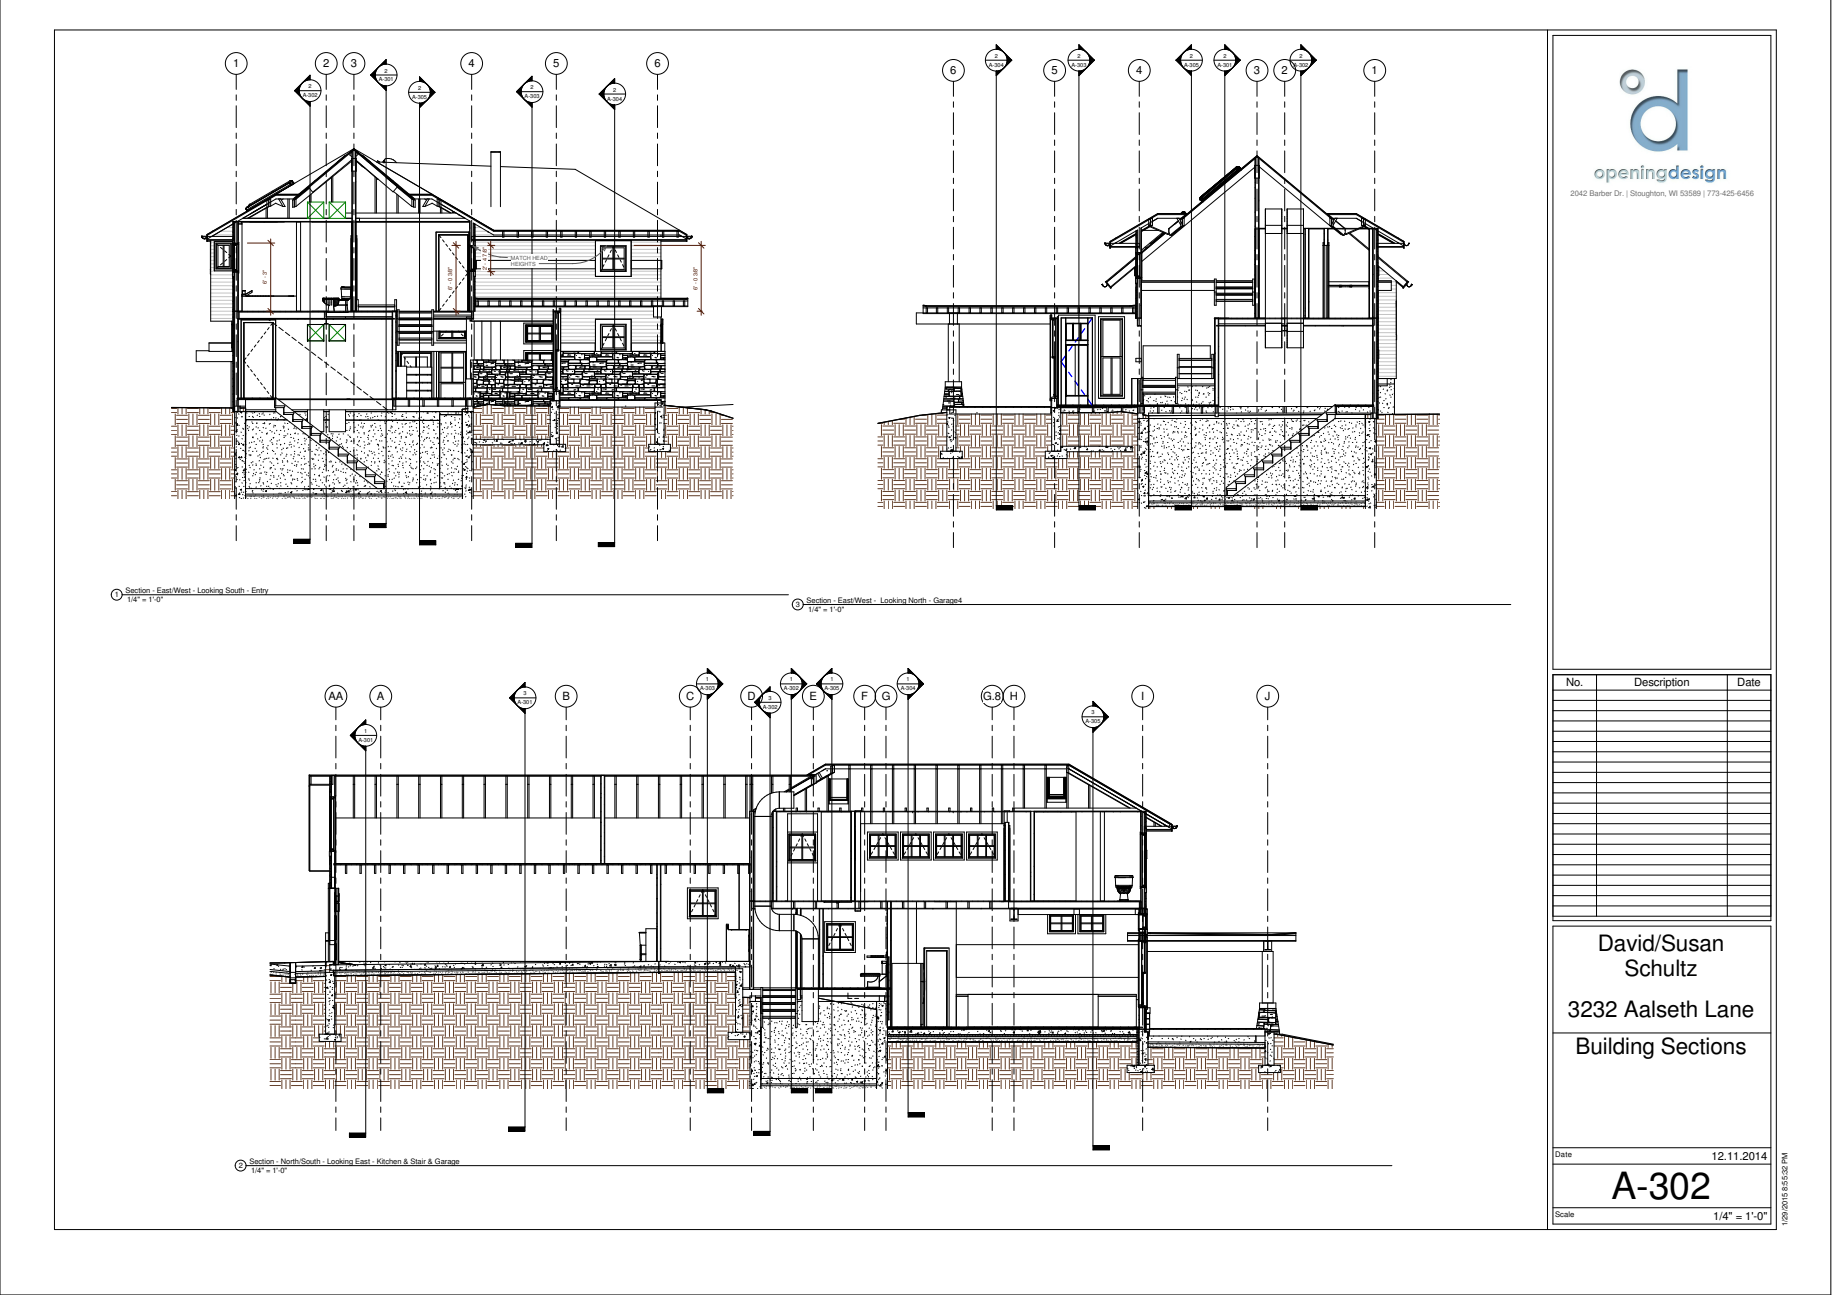
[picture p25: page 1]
MATCH HEAD HEIGHTS; Scale; Date; Building Sections; David/Susan Schultz; 3232 Aalseth Lane; Description

2042 Barber Dr. | Stoughton, WI 53589 | 773-425-6456

1/4" = 1'-0" 1 Section - East/West - Looking South - Entry

1/4" = 1'-0" 3 Section - East/West - Looking North - Garage4

1/4" = 1'-0" 2 Section - North/South - Looking East - Kitchen & Stair & Garage

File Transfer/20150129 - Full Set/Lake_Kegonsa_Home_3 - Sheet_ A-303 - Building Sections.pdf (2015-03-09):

2 | 4
1 | 3 | 5 | 6

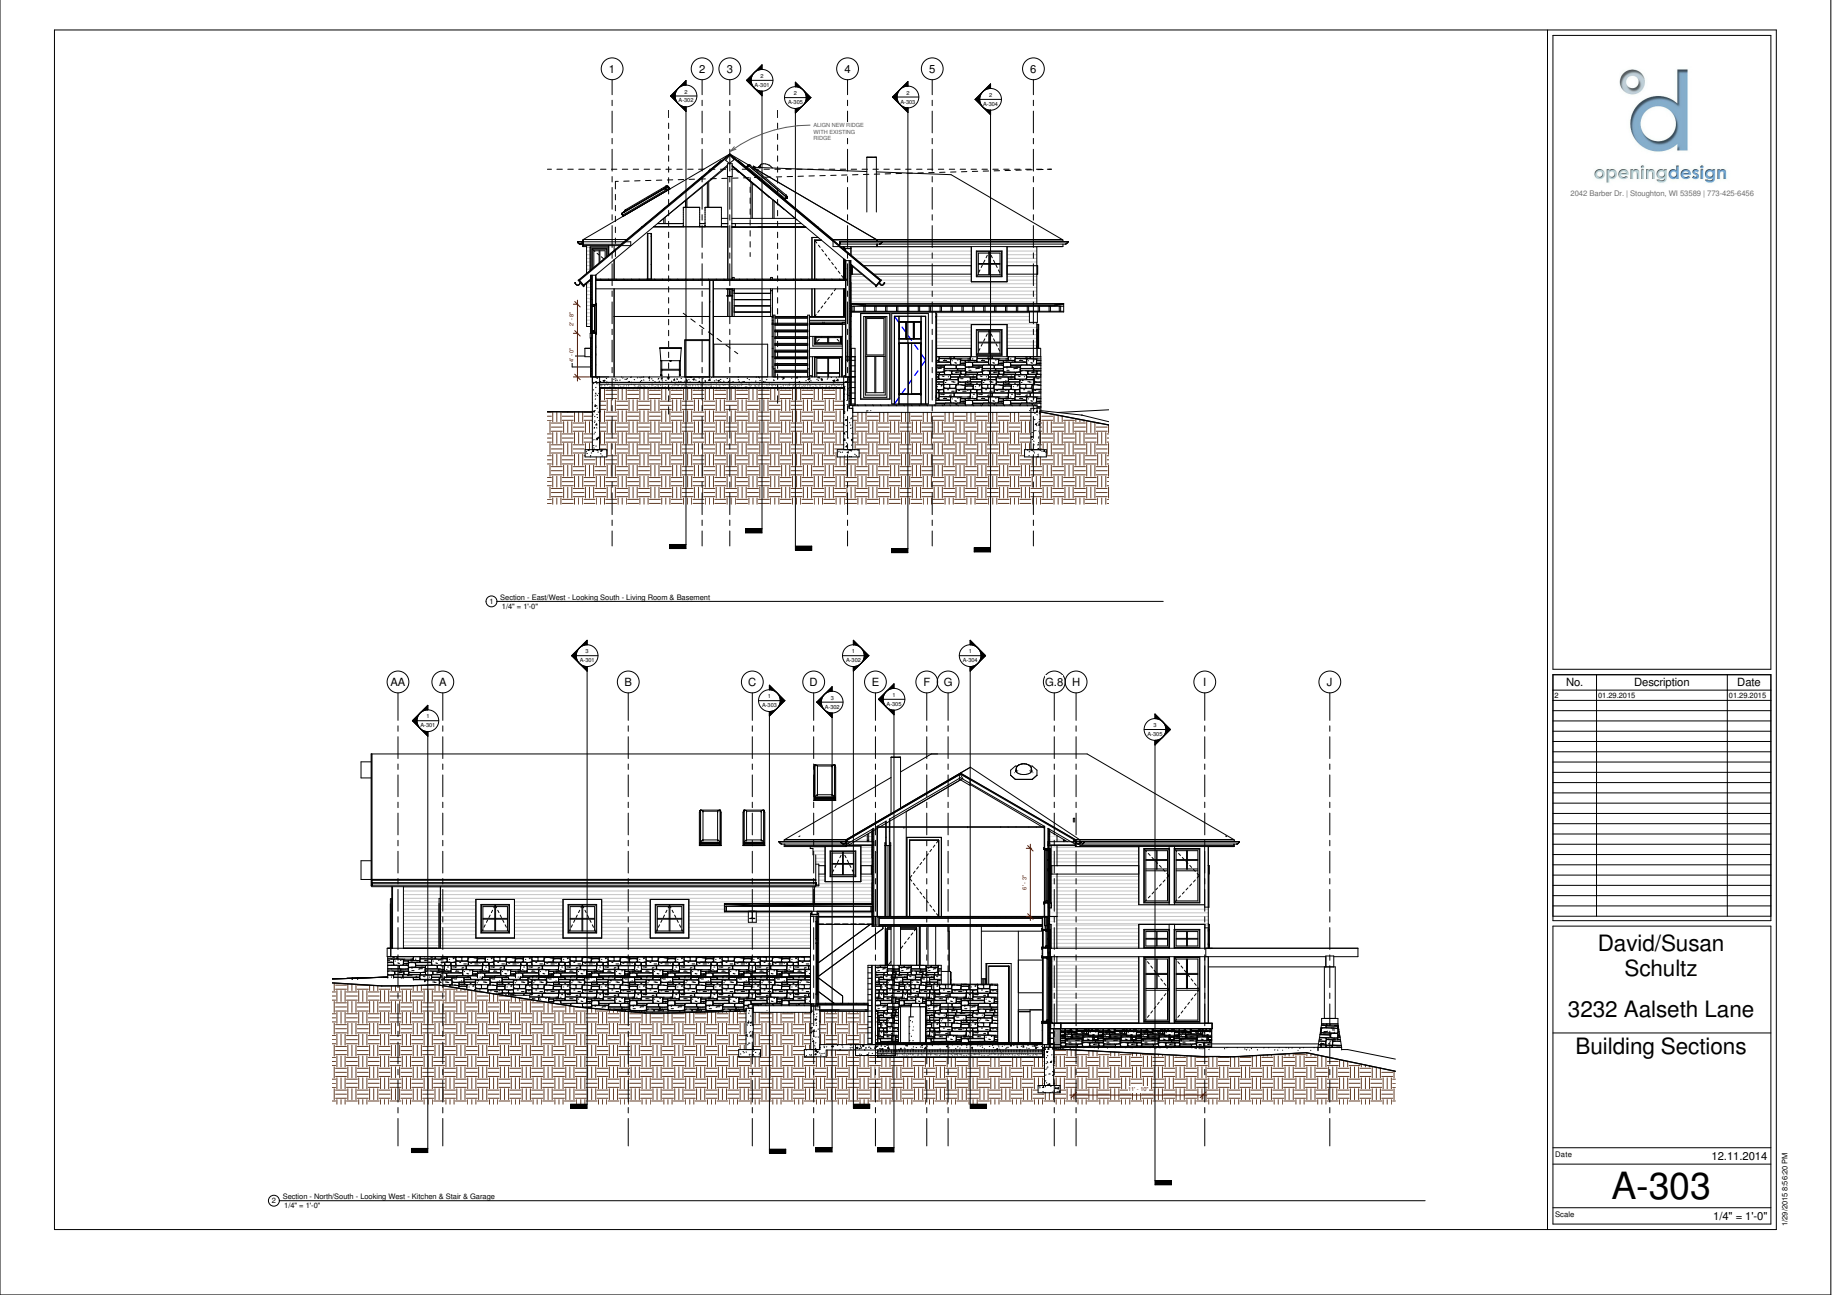
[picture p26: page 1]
Scale; Date; Building Sections; David/Susan Schultz; 3232 Aalseth Lane; Description

ALIGN NEW RIDGE
WITH EXISTING
RIDGE

2042 Barber Dr. | Stoughton, WI 53589 | 773-425-6456

1/4" = 1'-0" 1 Section - East/West - Looking South - Living Room & Basement

1/4" = 1'-0" 2 Section - North/South - Looking West - Kitchen & Stair & Garage

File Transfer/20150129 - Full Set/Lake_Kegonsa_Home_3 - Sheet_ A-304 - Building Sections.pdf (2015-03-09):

2 | 4
1 | 3 | 5 | 6

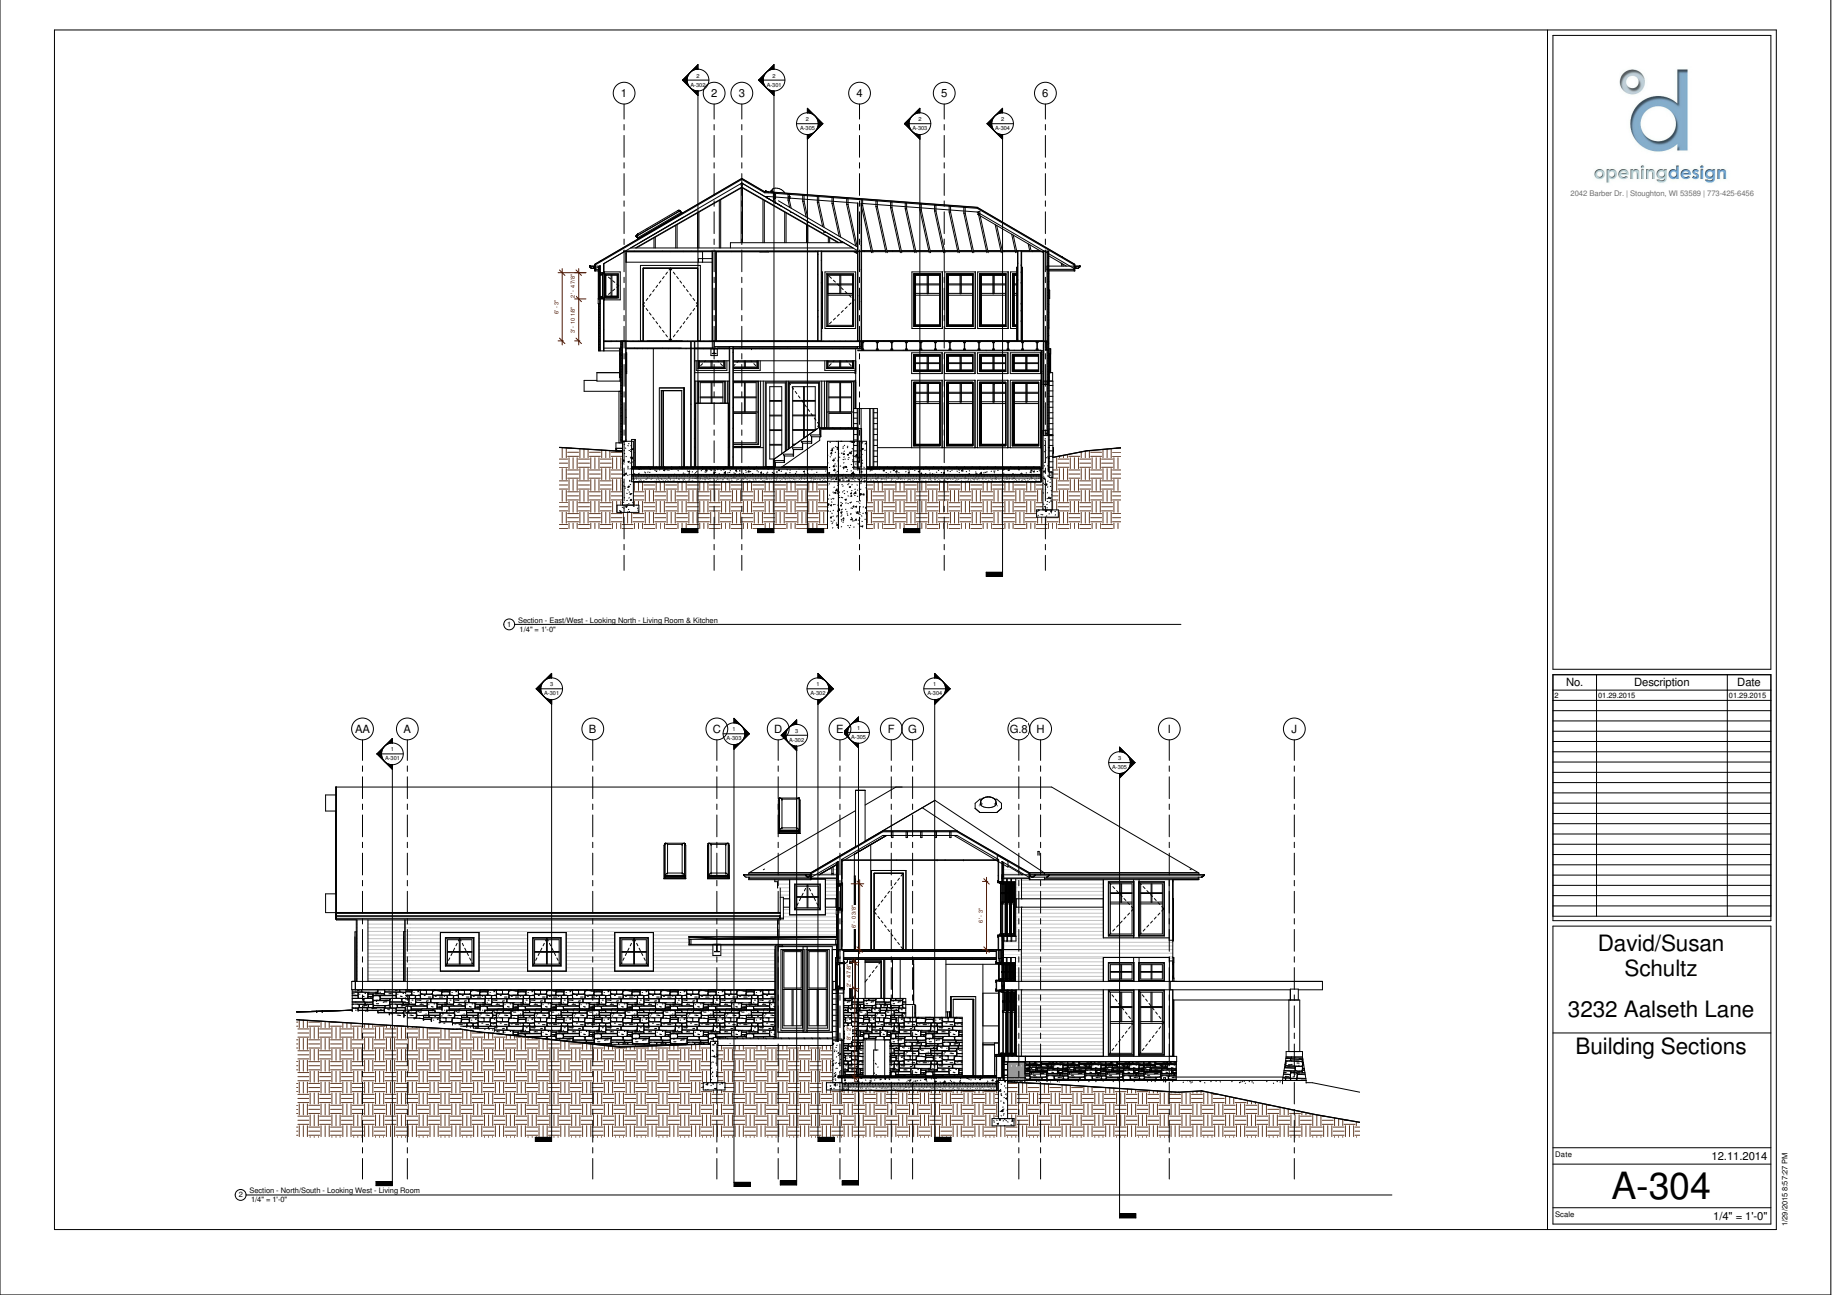
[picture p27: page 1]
Scale; Date; Building Sections; David/Susan Schultz; 3232 Aalseth Lane; Description

2042 Barber Dr. | Stoughton, WI 53589 | 773-425-6456

1/4" = 1'-0" 1 Section - East/West - Looking North - Living Room & Kitchen

1/4" = 1'-0" 2 Section - North/South - Looking West - Living Room

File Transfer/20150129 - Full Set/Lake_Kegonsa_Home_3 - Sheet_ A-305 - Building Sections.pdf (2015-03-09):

4 | 2
6 | 5 | 3 | 1

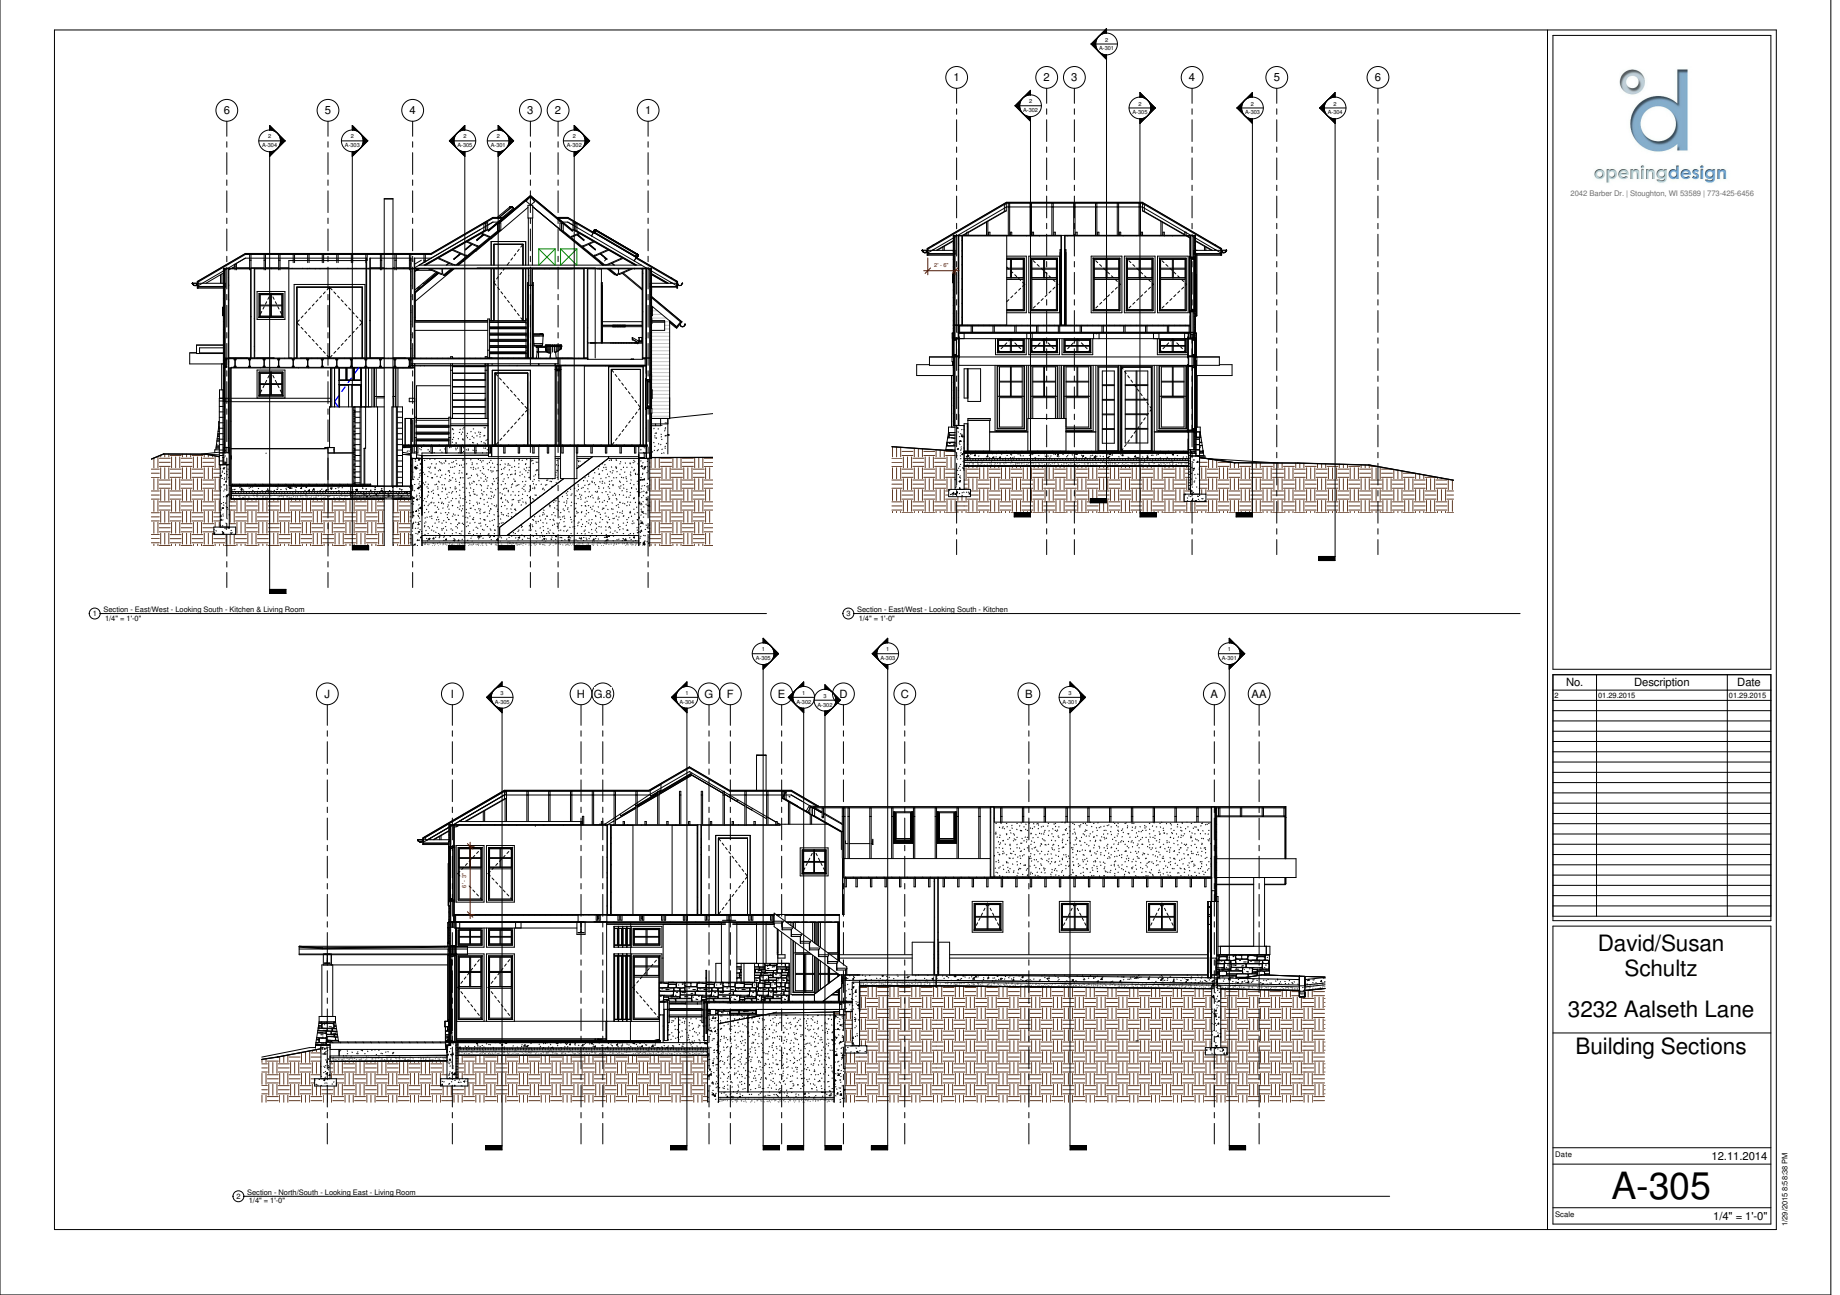
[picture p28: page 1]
Scale; Date; Building Sections; David/Susan Schultz; 3232 Aalseth Lane; Description

2042 Barber Dr. | Stoughton, WI 53589 | 773-425-6456

1/4" = 1'-0" 1 Section - East/West - Looking South - Kitchen & Living Room

1/4" = 1'-0" 3 Section - East/West - Looking South - Kitchen

1/4" = 1'-0" 2 Section - North/South - Looking East - Living Room

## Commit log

2014-09-04 progress shot
    [Twin.dwg, survey.dwg]
2014-09-13 progress snapshot
    [3232 Aalseth Lane - Site Plan.dwg]
2014-09-30 print to plumber
2014-10-21 structural collaboration
    [Twin.dwg]
2014-11-22 Analysis of beam at (H). Corrections.
    First text-based traceable changes
2014-12-01 survey stakeout
    [stakeout_ryan modified.dwg]
2014-12-11 lloyds plumbing/heating
    [lloyds_20141205_3232 Aalseth_°d-Sheet - A-101 - First Floor and Site Plan.dwg, lloyds_20141205_3232 Aalseth_°d-Sheet - A-102 - Second & Third Floor Plan.dwg, l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]
2017-05-31 before Boat House
    [7100fp.dxf, Colonial-Revival-Package.dwg, Colonial-Revival-Package.dxf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]
2017-08-25 Transfer\20170724 - from Paulson - Erosin Control
    [Sediment Discharge CalculationTool 6-20-17a.xls]
